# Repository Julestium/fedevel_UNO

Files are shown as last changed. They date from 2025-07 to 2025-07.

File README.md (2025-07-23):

# Arduino Uno Rev3 based PCB Design (Altium Designer)

This repository contains a complete **Arduino Uno Rev3 PCB design** based on the reference design from **Fedevel Academy**. It includes the full **schematic**, **PCB layout**, **assembly files**, **BOM (Bill of Materials)**, and **3D views**.

As part of my learning process, I manually recreated the schematic and implemented the PCB layout in Altium Designer. This project was intended as a personal exercise in schematic capture, layout, DRC management, variant handling, and preparing manufacturing outputs.

The goal of this project is to provide a **custom PCB design** that replicates the Arduino Uno Rev3 form factor and features, while offering a more professional approach to designing Arduino-based boards.

## Features
- Fully compatible with **Arduino Uno Rev3**
- Designed using **Altium Designer**
- Includes **3D view** of the PCB layout
- Detailed **schematic diagram** of the design
- Complete **Bill of Materials (BOM)**
- Ready-to-use **assembly files** for manufacturing

## Project Files
The following files are included in this repository:

- **Schematic**: Detailed circuit diagram in `.SchDoc` format
- **PCB Layout**: Fully routed PCB design in `.PcbDoc` format
- **Assembly Files**: Includes gerber files for manufacturing
- **BOM**: Complete Bill of Materials for easy component sourcing
- **3D View**: A 3D rendering of the PCB layout for visual inspection

### File Structure:
- `schematic/`: Contains the schematic design file (`.SchDoc`)
- `Assembly and 3D Models/`: Gerber files for PCB manufacturing , Bill of Materials and 3D render images of the PCB

### Schematic Diagram

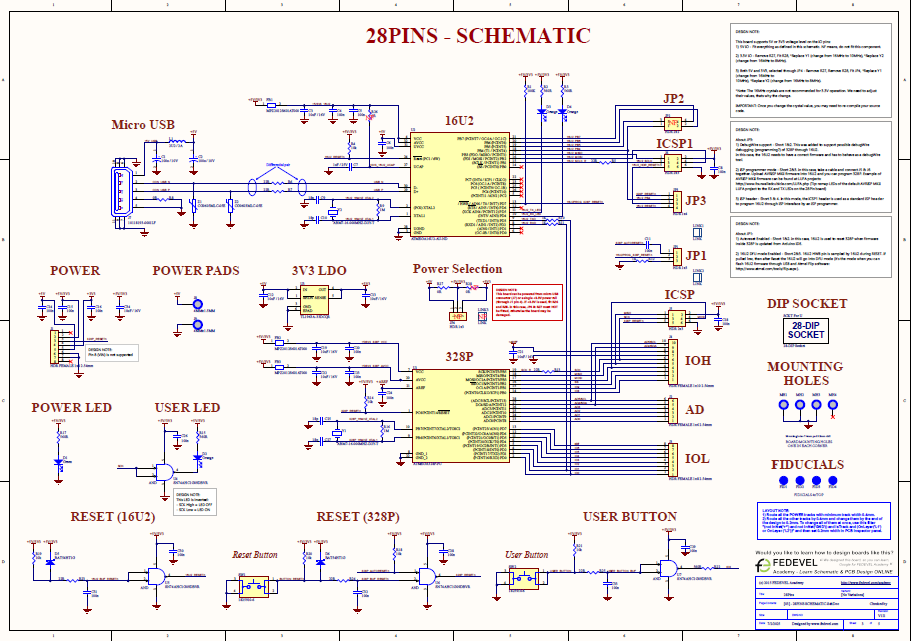
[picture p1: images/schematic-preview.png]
Schematic Preview
  

### PCB Layout

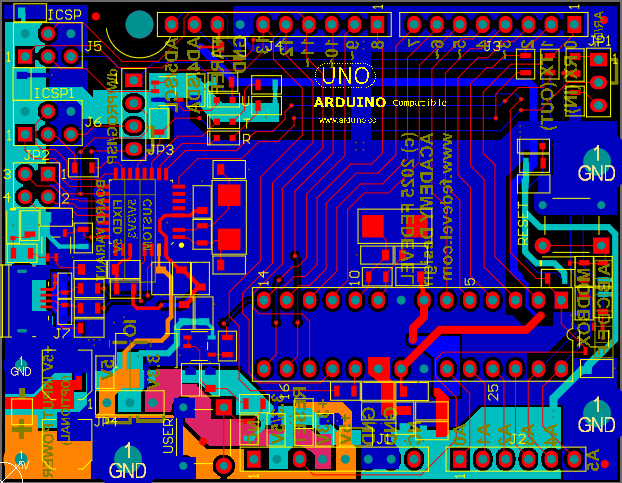
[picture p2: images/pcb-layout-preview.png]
PCB Layout Preview
  <!-- Image of PCB layout preview -->

### 3D View of the PCB

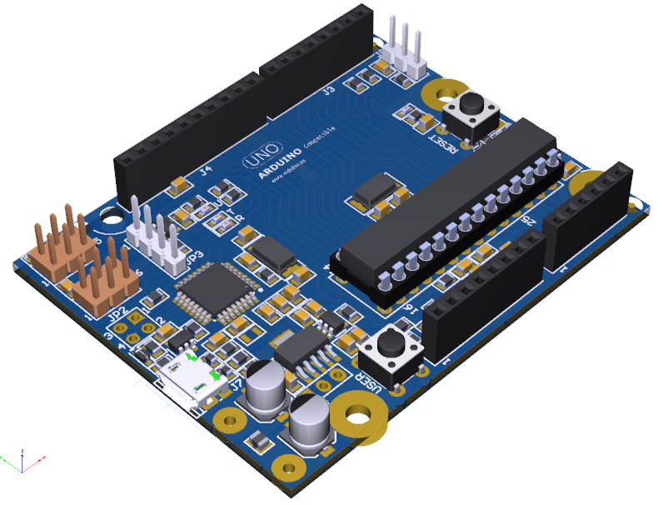
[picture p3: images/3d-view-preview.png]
3D View Preview
 

## Build Instructions

### Step 1: Manufacturing the PCB
1. Download the **Gerber files** from the `assembly/` folder.
2. Use these files to send to your preferred PCB manufacturer.

### Step 2: Assembling the Components
1. Once you have the PCB, begin the assembly by following the **Bill of Materials (BOM)**.
2. Solder the components according to the **schematic** and **PCB layout**.
3. Ensure all connections are made correctly, especially power and ground connections.

### Step 3: Testing the Board
Once the board is assembled:
1. Connect it to a computer or USB power supply.
2. Load the standard **Arduino Uno sketch** onto the board to verify that it functions correctly.

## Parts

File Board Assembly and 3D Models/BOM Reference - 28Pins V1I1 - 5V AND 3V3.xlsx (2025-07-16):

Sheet: Part List Report
 | Component reference list |  |  | 28Pins
 |  | Source Data From: | 28Pins_Project_V1I1.PrjPcb |  | Contact: |  | Generated by:
 |  | Project: | 28Pins_Project_V1I1.PrjPcb |  | LinkedIn (https://www.linkedin.com/in/mahla-gholami-4b0013294/)
 |  | Variant: | 5V/3V3 |  |  |  | M. Gholami
 | Report Date: | 7/1/2025 | 1:36 PM
 | Print Date: | 2025-07-01 | 14:52:56
# | Designator | Comment | Description | Manufacturer | Manufacturer Part Number | Case/Package | Supplier | Supplier Part Number
1 | C1 | 100u / 10V | Aluminum Electrolytic Capacitor, 100 uF, 10 V, ± 20%, 1000 hours @ 85°C, Radial Can - SMD | Panasonic | EEE-1AA101WR | Radial | Digikey | PCE3867CT-ND
2 | C2 | 100u / 10V | Aluminum Electrolytic Capacitor, 100 uF, 10 V, ± 20%, 1000 hours @ 85°C, Radial Can - SMD | Panasonic | EEE-1AA101WR | Radial | Digikey | PCE3867CT-ND
3 | C3 | 10uF / 16V | Multilayer Ceramic Capacitor, 10 uF, 16 V, ± 20%, X5R, 0805 [2012 Metric] | TDK | CGA4J1X5R1C106M125AC |  | Digikey | 445-12654-1-ND
4 | C4 | 100n | Multilayer Ceramic Capacitor, 0.1 uF, 50 V, ± 10%, X7R, 0805 [2012 Metric] | TDK | C2012X7R1H104K085AA | 0805 | Digikey | 445-7534-1-ND
5 | C5 | 100n | Multilayer Ceramic Capacitor, 0.1 uF, 50 V, ± 10%, X7R, 0805 [2012 Metric] | TDK | C2012X7R1H104K085AA | 0805 | Digikey | 445-7534-1-ND
6 | C6 | 100n | Multilayer Ceramic Capacitor, 0.1 uF, 50 V, ± 10%, X7R, 0805 [2012 Metric] | TDK | C2012X7R1H104K085AA | 0805 | Digikey | 445-7534-1-ND
7 | C7 | 1uF / 25V | CAP CER 1UF 25V X5R 0805 | TDK | C2012X5R1E105K125AA |  | Digikey | 445-1419-1-ND
8 | C8 | 100n | Multilayer Ceramic Capacitor, 0.1 uF, 50 V, ± 10%, X7R, 0805 [2012 Metric] | TDK | C2012X7R1H104K085AA | 0805 | Digikey | 445-7534-1-ND
9 | C9 | 18p | SMD Comm C0G 0805 (2012Metric) Ceramic Capacitor 0.079Lx0.049W 2.00mmx1.25mm C0G NP0 ±5% 18pF | KEMET | C0805C180J5GACTU | 0805 | Digikey | 399-C0805C180J5GACTUCT-ND
10 | C10 | 18p | SMD Comm C0G 0805 (2012Metric) Ceramic Capacitor 0.079Lx0.049W 2.00mmx1.25mm C0G NP0 ±5% 18pF | KEMET | C0805C180J5GACTU | 0805 | Digikey | 399-C0805C180J5GACTUCT-ND
11 | C11 | 100n | Multilayer Ceramic Capacitor, 0.1 uF, 50 V, ± 10%, X7R, 0805 [2012 Metric] | TDK | C2012X7R1H104K085AA | 0805 | Digikey | 445-7534-1-ND
12 | C12 | 10uF / 16V | Multilayer Ceramic Capacitor, 10 uF, 16 V, ± 20%, X5R, 0805 [2012 Metric] | TDK | CGA4J1X5R1C106M125AC |  | Digikey | 445-12654-1-ND
13 | C13 | 10uF / 16V | Multilayer Ceramic Capacitor, 10 uF, 16 V, ± 20%, X5R, 0805 [2012 Metric] | TDK | CGA4J1X5R1C106M125AC |  | Digikey | 445-12654-1-ND
14 | C14 | 100n | Multilayer Ceramic Capacitor, 0.1 uF, 50 V, ± 10%, X7R, 0805 [2012 Metric] | TDK | C2012X7R1H104K085AA | 0805 | Digikey | 445-7534-1-ND
15 | C15 | 100n | Multilayer Ceramic Capacitor, 0.1 uF, 50 V, ± 10%, X7R, 0805 [2012 Metric] | TDK | C2012X7R1H104K085AA | 0805 | Digikey | 445-7534-1-ND
16 | C16 | 100n | Multilayer Ceramic Capacitor, 0.1 uF, 50 V, ± 10%, X7R, 0805 [2012 Metric] | TDK | C2012X7R1H104K085AA | 0805 | Digikey | 445-7534-1-ND
17 | C18 | 100n | Multilayer Ceramic Capacitor, 0.1 uF, 50 V, ± 10%, X7R, 0805 [2012 Metric] | TDK | C2012X7R1H104K085AA | 0805 | Digikey | 445-7534-1-ND
18 | C19 | 10uF / 16V | Multilayer Ceramic Capacitor, 10 uF, 16 V, ± 20%, X5R, 0805 [2012 Metric] | TDK | CGA4J1X5R1C106M125AC |  | Digikey | 445-12654-1-ND
19 | C20 | 100n | Multilayer Ceramic Capacitor, 0.1 uF, 50 V, ± 10%, X7R, 0805 [2012 Metric] | TDK | C2012X7R1H104K085AA | 0805 | Digikey | 445-7534-1-ND
20 | C21 | 10uF / 16V | Multilayer Ceramic Capacitor, 10 uF, 16 V, ± 20%, X5R, 0805 [2012 Metric] | TDK | CGA4J1X5R1C106M125AC |  | Digikey | 445-12654-1-ND
21 | C22 | 10uF / 16V | Multilayer Ceramic Capacitor, 10 uF, 16 V, ± 20%, X5R, 0805 [2012 Metric] | TDK | CGA4J1X5R1C106M125AC |  | Digikey | 445-12654-1-ND
22 | C23 | 100n | Multilayer Ceramic Capacitor, 0.1 uF, 50 V, ± 10%, X7R, 0805 [2012 Metric] | TDK | C2012X7R1H104K085AA | 0805 | Digikey | 445-7534-1-ND
23 | C24 | 100n | Multilayer Ceramic Capacitor, 0.1 uF, 50 V, ± 10%, X7R, 0805 [2012 Metric] | TDK | C2012X7R1H104K085AA | 0805 | Digikey | 445-7534-1-ND
24 | C25 | 18p | SMD Comm C0G 0805 (2012Metric) Ceramic Capacitor 0.079Lx0.049W 2.00mmx1.25mm C0G NP0 ±5% 18pF | KEMET | C0805C180J5GACTU | 0805 | Digikey | 399-C0805C180J5GACTUCT-ND
25 | C26 | 100n | Multilayer Ceramic Capacitor, 0.1 uF, 50 V, ± 10%, X7R, 0805 [2012 Metric] | TDK | C2012X7R1H104K085AA | 0805 | Digikey | 445-7534-1-ND
26 | C27 | 18p | SMD Comm C0G 0805 (2012Metric) Ceramic Capacitor 0.079Lx0.049W 2.00mmx1.25mm C0G NP0 ±5% 18pF | KEMET | C0805C180J5GACTU | 0805 | Digikey | 399-C0805C180J5GACTUCT-ND
27 | C28 | 100n | Multilayer Ceramic Capacitor, 0.1 uF, 50 V, ± 10%, X7R, 0805 [2012 Metric] | TDK | C2012X7R1H104K085AA | 0805 | Digikey | 445-7534-1-ND
28 | C29 | 100n | Multilayer Ceramic Capacitor, 0.1 uF, 50 V, ± 10%, X7R, 0805 [2012 Metric] | TDK | C2012X7R1H104K085AA | 0805 | Digikey | 445-7534-1-ND
29 | C30 | 100n | Multilayer Ceramic Capacitor, 0.1 uF, 50 V, ± 10%, X7R, 0805 [2012 Metric] | TDK | C2012X7R1H104K085AA | 0805 | Digikey | 445-7534-1-ND
30 | C31 | 100n | Multilayer Ceramic Capacitor, 0.1 uF, 50 V, ± 10%, X7R, 0805 [2012 Metric] | TDK | C2012X7R1H104K085AA | 0805 | Digikey | 445-7534-1-ND
31 | C32 | 100n | Multilayer Ceramic Capacitor, 0.1 uF, 50 V, ± 10%, X7R, 0805 [2012 Metric] | TDK | C2012X7R1H104K085AA | 0805 | Digikey | 445-7534-1-ND
32 | C33 | 100n | Multilayer Ceramic Capacitor, 0.1 uF, 50 V, ± 10%, X7R, 0805 [2012 Metric] | TDK | C2012X7R1H104K085AA | 0805 | Digikey | 445-7534-1-ND
33 | C34 | 10uF / 16V | Multilayer Ceramic Capacitor, 10 uF, 16 V, ± 20%, X5R, 0805 [2012 Metric] | TDK | CGA4J1X5R1C106M125AC |  | Digikey | 445-12654-1-ND
34 | D1 | Green | Green 525nm LED Indication - Discrete 2.65V 0603 (1608 Metric) | Kingbright | APT1608LZGCK | 0603 | Digikey | 754-1934-1-ND
35 | D2 | Orange | LED Uni-Color Orange 2-Pin Chip 0603(1608Metric) T/R | Rohm | CSL1901DW1 |  | Digikey | 846-CSL1901DW1CT-ND
36 | D3 | Orange | LED Uni-Color Orange 2-Pin Chip 0603(1608Metric) T/R | Rohm | CSL1901DW1 |  | Digikey | 846-CSL1901DW1CT-ND
37 | D4 | Orange | LED Uni-Color Orange 2-Pin Chip 0603(1608Metric) T/R | Rohm | CSL1901DW1 |  | Digikey | 846-CSL1901DW1CT-ND
38 | D5 | BAT54HT1G | Small Signal Schottky Diode, Single, 30 V, 200 Ma, 800 Mv, 600 Ma, 150 C | ON Semiconductor / Fairchild | BAT54HT1G |  | Digikey | BAT54HT1GOSCT-ND
39 | D6 | BAT54HT1G | Small Signal Schottky Diode, Single, 30 V, 200 Ma, 800 Mv, 600 Ma, 150 C | ON Semiconductor / Fairchild | BAT54HT1G |  | Digikey | BAT54HT1GOSCT-ND
40 | FB1 | MPZ2012S601AT000 | Ferrite Beads Multi-Layer Power 600Ohm 25% 100MHz 2A 100mOhm DCR 0805 T/R | TDK | MPZ2012S601AT000 | 0805 | Digikey | 445-MPZ2012S601AT000CT-ND
41 | FB2 | MPZ2012S601AT000 | Ferrite Beads Multi-Layer Power 600Ohm 25% 100MHz 2A 100mOhm DCR 0805 T/R | TDK | MPZ2012S601AT000 | 0805 | Digikey | 445-MPZ2012S601AT000CT-ND
42 | FB3 | MPZ2012S601AT000 | Ferrite Beads Multi-Layer Power 600Ohm 25% 100MHz 2A 100mOhm DCR 0805 T/R | TDK | MPZ2012S601AT000 | 0805 | Digikey | 445-MPZ2012S601AT000CT-ND
43 | J1 | HDR FEMALE 1x8 2.54mm | 2.54mm (0.1") Pitch SIL Vertical PC Tail Socket Assembly, selective gold + tin, 8 contacts | Harwin | M20-7820842 | SIL | Digikey | 952-1823-ND
44 | J2 | HDR FEMALE 1x6 2.54mm | 2.54mm (0.1") Pitch SIL Vertical PC Tail Socket Assembly, tin, 6 contacts | Harwin | M20-7820646 | SIL | Digikey | 952-1809-ND
45 | J3 | HDR FEMALE 1x8 2.54mm | 2.54mm (0.1") Pitch SIL Vertical PC Tail Socket Assembly, selective gold + tin, 8 contacts | Harwin | M20-7820842 | SIL | Digikey | 952-1823-ND
46 | J4 | HDR FEMALE 1x10 2.54mm | 2.54mm (0.1") Pitch SIL Vertical PC Tail Socket Assembly, tin, 10 contacts | Harwin | M20-7821046 |  | Digikey | 952-1847-ND
47 | J5 | HDR 2x3 | Conn Unshrouded Header HDR 6 POS 2.54mm Solder ST Top Entry Thru-Hole BergStik® Bulk | Amphenol ICC / FCI | 67997-106HLF |  | Digikey | 609-3393-ND
48 | J6 | HDR 2x3 | Conn Unshrouded Header HDR 6 POS 2.54mm Solder ST Top Entry Thru-Hole BergStik® Bulk | Amphenol ICC / FCI | 67997-106HLF |  | Digikey | 609-3393-ND
49 | J7 | 10118193-0001LF | FCI Right Angle Surface Mount Mount Female USB Connector; 100 V ac; 1.8A | Amphenol ICC / FCI | 10118193-0001LF |  | Digikey | 609-4616-1-ND
50 | JP1 | HDR 1x3 | Conn Unshrouded Header HDR 3 POS 2.54mm Solder ST Top Entry Thru-Hole BergStik® Automotive Bulk | Amphenol ICC / FCI | 68000-103HLF |  | Digikey | 609-3461-ND
51 | JP3 | HDR 1x4 | Conn Unshrouded Header HDR 4 POS 2.54mm Solder ST Thru-Hole Bag | Amphenol ICC / FCI | 68001-204HLF |  | Digikey | 609-3402-ND
52 | JP4 | HDR 1x3 | Conn Unshrouded Header HDR 3 POS 2.54mm Solder ST Top Entry Thru-Hole BergStik® Automotive Bulk | Amphenol ICC / FCI | 68000-103HLF |  | Digikey | 609-3461-ND
53 | L1 | 2U2 / 2A | Inductor Power Shielded Wirewound 2.2uH 20% 1MHz Metal 1.4A 0.168Ohm DCR 0806 T/R | Murata | DFE201610P-2R2M=P2 | 0806 | Digikey | 490-10609-1-ND
54 | LINK1 | LINK | 2 Position 2.54 mm Centerline Single Circuit Open Top Jumper | Sullins | QPC02SXGN-RC |  | Digikey | S9337-ND
55 | LINK2 | LINK | 2 Position 2.54 mm Centerline Single Circuit Open Top Jumper | Sullins | QPC02SXGN-RC |  | Digikey | S9337-ND
56 | LINK3 | LINK | 2 Position 2.54 mm Centerline Single Circuit Open Top Jumper | Sullins | QPC02SXGN-RC |  | Digikey | S9337-ND
57 | R1 | 100K | 125Mw Thick Film Resistors 100Ppm/ 1% 100K 0805 Chip Resistor Surface Mount Rohs | Yageo | RC0805FR-07100KL | 0805 | Digikey | 311-100KCRCT-ND
58 | R2 | 560R | Res General Purpose Thick Film 0805 560 Ohm 1% 1/8W ±100ppm/°C Molded Paper T/R | Yageo | RC0805FR-07560RL |  | Digikey | 311-560CRCT-ND
59 | R3 | 560R | Res General Purpose Thick Film 0805 560 Ohm 1% 1/8W ±100ppm/°C Molded Paper T/R | Yageo | RC0805FR-07560RL |  | Digikey | 311-560CRCT-ND
60 | R4 | 10k | Res Thick Film 0805 10K Ohm 1% 0.125W(1/8W) +/-100ppm/C Epoxy Pad SMD T/R | Yageo | RC0805FR-0710KL | 0805 | Digikey | 311-10.0KCRCT-ND
61 | R5 | 22R | SMD Chip Resistor, 22 Ohm, ± 1%, 125 mW, 0805 [2012 Metric], Thick Film, General Purpose | Yageo | RC0805FR-0722RL |  | Digikey | 311-22.0CRCT-ND
62 | R6 | 22R | SMD Chip Resistor, 22 Ohm, ± 1%, 125 mW, 0805 [2012 Metric], Thick Film, General Purpose | Yageo | RC0805FR-0722RL |  | Digikey | 311-22.0CRCT-ND
63 | R7 | 22R | SMD Chip Resistor, 22 Ohm, ± 1%, 125 mW, 0805 [2012 Metric], Thick Film, General Purpose | Yageo | RC0805FR-0722RL |  | Digikey | 311-22.0CRCT-ND
64 | R8 | 0R | GENERAL PURPOSE CHIP RESISTOR Metal Glaze/thick Film, 0.125W, 0ohm, Surface Mount, 0805 | Yageo | RC0805JR-070RL | 0805 | Digikey | 311-0.0ARCT-ND
65 | R9 | 1M | 125Mw Thick Film Resistors 100Ppm/ 1% 1M 0805 Chip Resistor Surface Mount Rohs | Yageo | RC0805FR-071ML | Molded | Digikey | 311-1.00MCRCT-ND
66 | R10 | 1K | 125Mw Thick Film Resistors 100Ppm/ 1% 1K 0805 Chip Resistor Surface Mount Rohs | Yageo | RC0805FR-071KL | 0805 | Digikey | 311-1.00KCRCT-ND
67 | R11 | 1K | 125Mw Thick Film Resistors 100Ppm/ 1% 1K 0805 Chip Resistor Surface Mount Rohs | Yageo | RC0805FR-071KL | 0805 | Digikey | 311-1.00KCRCT-ND
68 | R12 | 1K | 125Mw Thick Film Resistors 100Ppm/ 1% 1K 0805 Chip Resistor Surface Mount Rohs | Yageo | RC0805FR-071KL | 0805 | Digikey | 311-1.00KCRCT-ND
69 | R13 | 22R | SMD Chip Resistor, 22 Ohm, ± 1%, 125 mW, 0805 [2012 Metric], Thick Film, General Purpose | Yageo | RC0805FR-0722RL |  | Digikey | 311-22.0CRCT-ND
70 | R14 | 10k | Res Thick Film 0805 10K Ohm 1% 0.125W(1/8W) +/-100ppm/C Epoxy Pad SMD T/R | Yageo | RC0805FR-0710KL | 0805 | Digikey | 311-10.0KCRCT-ND
71 | R15 | 560R | Res General Purpose Thick Film 0805 560 Ohm 1% 1/8W ±100ppm/°C Molded Paper T/R | Yageo | RC0805FR-07560RL |  | Digikey | 311-560CRCT-ND
72 | R16 | 1M | 125Mw Thick Film Resistors 100Ppm/ 1% 1M 0805 Chip Resistor Surface Mount Rohs | Yageo | RC0805FR-071ML | Molded | Digikey | 311-1.00MCRCT-ND
73 | R17 | 560R | Res General Purpose Thick Film 0805 560 Ohm 1% 1/8W ±100ppm/°C Molded Paper T/R | Yageo | RC0805FR-07560RL |  | Digikey | 311-560CRCT-ND
74 | R18 | 10k | Res Thick Film 0805 10K Ohm 1% 0.125W(1/8W) +/-100ppm/C Epoxy Pad SMD T/R | Yageo | RC0805FR-0710KL | 0805 | Digikey | 311-10.0KCRCT-ND
75 | R19 | 10k | Res Thick Film 0805 10K Ohm 1% 0.125W(1/8W) +/-100ppm/C Epoxy Pad SMD T/R | Yageo | RC0805FR-0710KL | 0805 | Digikey | 311-10.0KCRCT-ND
76 | R20 | 10k | Res Thick Film 0805 10K Ohm 1% 0.125W(1/8W) +/-100ppm/C Epoxy Pad SMD T/R | Yageo | RC0805FR-0710KL | 0805 | Digikey | 311-10.0KCRCT-ND
77 | R21 | 10k | Res Thick Film 0805 10K Ohm 1% 0.125W(1/8W) +/-100ppm/C Epoxy Pad SMD T/R | Yageo | RC0805FR-0710KL | 0805 | Digikey | 311-10.0KCRCT-ND
78 | R22 | 560R | Res General Purpose Thick Film 0805 560 Ohm 1% 1/8W ±100ppm/°C Molded Paper T/R | Yageo | RC0805FR-07560RL |  | Digikey | 311-560CRCT-ND
79 | R23 | 22R | SMD Chip Resistor, 22 Ohm, ± 1%, 125 mW, 0805 [2012 Metric], Thick Film, General Purpose | Yageo | RC0805FR-0722RL |  | Digikey | 311-22.0CRCT-ND
80 | R24 | 22R | SMD Chip Resistor, 22 Ohm, ± 1%, 125 mW, 0805 [2012 Metric], Thick Film, General Purpose | Yageo | RC0805FR-0722RL |  | Digikey | 311-22.0CRCT-ND
81 | R25 | 22R | SMD Chip Resistor, 22 Ohm, ± 1%, 125 mW, 0805 [2012 Metric], Thick Film, General Purpose | Yageo | RC0805FR-0722RL |  | Digikey | 311-22.0CRCT-ND
82 | SCKT For U | 28-DIP Socket | Socket DIP 28Cnts DualWipe 0.3InSpc. PhosphorBronze Nickel KinkedTail 4800Series | 3M 4828-3004-CP | 3M | 4828-3004-CP |  | Digikey | 3M5480-ND
83 | SW1 | 1825910-6 | Switch Tactile OFF (ON) SPST Round Button PC Pins 0.05A 24VDC 1.57N Thru-Hole Loose | TE Connectivity Alcoswitch | 1825910-6 |  | Digikey | 450-1650-ND
84 | SW2 | 1825910-6 | Switch Tactile OFF (ON) SPST Round Button PC Pins 0.05A 24VDC 1.57N Thru-Hole Loose | TE Connectivity Alcoswitch | 1825910-6 |  | Digikey | 450-1650-ND
85 | U1 | ATMEGA328P-PU | Microchip - ATMEGA328P-PU - Microcontroller Mcu, 8 Bit, Atmega, 20MHZ, DIP-28 | Microchip | ATMEGA328P-PU | 28-DIP (0.300", 7.62mm) | Digikey | ATMEGA328P-PU-ND
86 | U2 | ATMEGA16U2-AU-ND | Risc Microcontroller, 8-BIT, Flash, AVR Risc Cpu, 16MHZ, Cmos, PQFP32 | Microchip | ATMEGA16U2-AU | 32-TQFP | Digikey | ATMEGA16U2-AU-ND
87 | U3 | TL1963A-33DCQR | LDO Regulator Pos 3.3V 1.5A 6-Pin(5+Tab) SOT-223 T/R | Texas Instruments | TL1963A-33DCQR | SOT-223-6 | Digikey | 296-24534-1-ND
88 | U4 | SN74AHC1G09DBVR | 1-ch, 2-input 2-V to 5.5-V high-speed (9 ns) AND gate with open-drain outputs 5-SOT-23 -55 to 125 | Texas Instruments | SN74AHC1G09DBVR | SOT-23 | Digikey | 296-29202-1-ND
89 | U5 | SN74AHC1G09DBVR | 1-ch, 2-input 2-V to 5.5-V high-speed (9 ns) AND gate with open-drain outputs 5-SOT-23 -55 to 125 | Texas Instruments | SN74AHC1G09DBVR | SOT-23 | Digikey | 296-29202-1-ND
90 | U6 | SN74AHC1G09DBVR | 1-ch, 2-input 2-V to 5.5-V high-speed (9 ns) AND gate with open-drain outputs 5-SOT-23 -55 to 125 | Texas Instruments | SN74AHC1G09DBVR | SOT-23 | Digikey | 296-29202-1-ND
91 | U7 | SN74AHC1G09DBVR | 1-ch, 2-input 2-V to 5.5-V high-speed (9 ns) AND gate with open-drain outputs 5-SOT-23 -55 to 125 | Texas Instruments | SN74AHC1G09DBVR | SOT-23 | Digikey | 296-29202-1-ND
92 | Y1 |  | Crystal 10MHz ±20ppm (Tol) ±30ppm (Stability) 18pF FUND 80Ohm 2-Pin Mini-CSMD T/R | Abracon | ABM7-10.000MHZ-D2Y-T |  | Digikey | 535-9833-1-ND
93 | Y2 |  | Crystal 8MHz ±20ppm (Tol) ±30ppm (Stability) 18pF FUND 100Ohm 2-Pin Mini-CSMD T/R | Abracon | ABM7-8.000MHZ-D2Y-T |  | Digikey | 535-9831-1-ND
94 | Z1 | CG0603MLC-05E | ESD Suppressor Multilayer Varistor 5V Automotive 2-Pin Case 0603(1608Metric) T/R | Bourns | CG0603MLC-05E | 0603 | Digikey | CG0603MLC-05ECT-ND
95 | Z2 | CG0603MLC-05E | ESD Suppressor Multilayer Varistor 5V Automotive 2-Pin Case 0603(1608Metric) T/R | Bourns | CG0603MLC-05E | 0603 | Digikey | CG0603MLC-05ECT-ND
Approved |  |  |  | Notes

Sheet: Project Information
Project Full Path | E:\Elements\Apps\Altium\28Pins\!Design Files\V1I1\28Pins_Project_V1I1\28Pins_Project_V1I1.PrjPcb
Project Filename | 28Pins_Project_V1I1.PrjPcb
Variant Name | 5V/3V3
Data-Source Filename | 28Pins_Project_V1I1.PrjPcb
Data-Source Full Path | E:\Elements\Apps\Altium\28Pins\!Design Files\V1I1\28Pins_Project_V1I1\28Pins_Project_V1I1.PrjPcb
Title | 28Pins_Project_V1I1.PrjPcb
Total Quantity | 95
Report Time | 1:36 PM
Report Date | 7/1/2025
Report Date & Tine | 7/1/2025 1:36 PM
Output Name | 28Pins Component reference BOM
Output Type | BomReport
Output Generator Name | BOM
Output Generator Description | Bill of Materials

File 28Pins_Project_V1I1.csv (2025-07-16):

LIBRARYREFERENCE | FOOTPRINT1 | ACCURACY | ACTUATOR LENGTH | ACTUATOR MATERIAL | ACTUATOR TYPE | AVERAGE RECTIFIED CURRENT | BREAKDOWN VOLTAGE | CASE CODE (IMPERIAL) | CASE CODE (METRIC) | CASE/PACKAGE | CATEGORY | CLAMPING VOLTAGE | CLOCK FREQUENCY | COLOR | COMMENT | COMPONENTLINK10DESCRIPTION | COMPONENTLINK10URL | COMPONENTLINK11DESCRIPTION | COMPONENTLINK11URL | COMPONENTLINK1DESCRIPTION | COMPONENTLINK1URL | COMPONENTLINK2DESCRIPTION | COMPONENTLINK2URL | COMPONENTLINK3DESCRIPTION | COMPONENTLINK3URL | COMPONENTLINK4DESCRIPTION | COMPONENTLINK4URL | COMPONENTLINK5DESCRIPTION | COMPONENTLINK5URL | COMPONENTLINK6DESCRIPTION | COMPONENTLINK6URL | COMPONENTLINK7DESCRIPTION | COMPONENTLINK7URL | COMPONENTLINK8DESCRIPTION | COMPONENTLINK8URL | COMPONENTLINK9DESCRIPTION | COMPONENTLINK9URL | CONNECTOR TYPE | CONSTRUCTION | CONTACT CURRENT RATING | CONTACT FINISH - MATING | CONTACT GENDER | CONTACT MATERIAL | CONTACT MATING LENGTH | CONTACT PLATING | CONTACT POST LENGTH | CONTACT SHAPE | CONTACT TYPE | CORE ARCHITECTURE | CORE MATERIAL | CURRENT RATING | DATA BUS WIDTH | DC RESISTANCE (DCR) | DEPTH | DIAMETER | DIELECTRIC | DISSIPATION FACTOR | DOMINANT WAVELENGTH | DROPOUT VOLTAGE
10118193-0001LF | 10118193 |  |  |  |  |  |  |  |  |  | LDO |  |  | Black | 10118193-0001LF |  |  |  |  | https://cdn.amphenol-icc.com/media/wysiwyg/files/documentation/datasheet/inputoutput/io_usb_micro.pdf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 | https://cdn.amphenol-icc.com/media/wysiwyg/files/documentation/datasheet/inputoutput/io_usb_micro.pdf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 | https://cdn.amphenol-icc.com/media/wysiwyg/files/documentation/datasheet/inputoutput/io_usb_micro.pdf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 | https://cdn.amphenol-icc.com/media/wysiwyg/files/documentation/datasheet/inputoutput/io_usb_micro.pdf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 | https://cdn.amphenol-icc.com/media/wysiwyg/files/documentation/datasheet/inputoutput/io_usb_micro.pdf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 | https://cdn.amphenol-icc.com/media/wysiwyg/files/documentation/datasheet/inputoutput/io_usb_micro.pdf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 | https://datasheet.octopart.com/10118193-0001LF-Amphenol-Communications-Solutions-datasheet-96019471.pdf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 | https://datasheet.octopart.com/10118193-0001LF-Amphenol-Communications-Solutions-datasheet-96019471.pdf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 | https://cdn.amphenol-icc.com/media/wysiwyg/files/documentation/datasheet/inputoutput/io_usb_micro.pdf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 | https://cdn.amphenol-icc.com/media/wysiwyg/files/documentation/datasheet/inputoutput/io_usb_micro.pdf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 | https://cdn.amphenol-icc.com/media/wysiwyg/files/documentation/datasheet/inputoutput/io_usb_micro.pdf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 | https://cdn.amphenol-icc.com/media/wysiwyg/files/documentation/datasheet/inputoutput/io_usb_micro.pdf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 | https://datasheet.octopart.com/10118193-0001LF-Amphenol-Communications-Solutions-datasheet-11792339.pdf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 | https://datasheet.octopart.com/10118193-0001LF-Amphenol-Communications-Solutions-datasheet-11792339.pdf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 | https://datasheet.octopart.com/10118193-0001LF-Amphenol-Communications-Solutions-datasheet-55953155.pdf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 | https://datasheet.octopart.com/10118193-0001LF-Amphenol-Communications-Solutions-datasheet-55953155.pdf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 |  |  | USB,Receptacle |  |  |  |  | Copper Alloy |  | Gold |  |  |  |  |  | 1.8A |  |  | 5.67mm
1825910-6 | 1825910-6 |  | 0.055inch | PBT | Standard |  |  |  |  |  | Pushbutton Switches |  |  | 46Colour | 1825910-6 |  |  |  |  |  |  |  |  |  |  |  |  |  |  |  |  |  |  |  |  |  |  |  |  | 50mA |  |  | Copper Alloy |  | Silver |  |  |  |  |  | 50mA
4828-3004-CP | 28-DIP_7.62mm_SOCKET |  |  |  |  |  |  |  |  |  | Connectors |  |  |  | 28-DIP Socket |  |  |  |  | https://datasheet.ciiva.com/768/ts1099-768354.pdf?src-supplier=Digikey | https://datasheet.ciiva.com/768/ts1099-768354.pdf?src-supplier=Digikey
67997-106HLF | HDR_2X3_2.54mm |  |  |  |  |  |  |  |  |  | Headers and Wire Housings |  |  |  | HDR 2x3 | https://cdn.amphenol-icc.com/media/wysiwyg/files/drawing/67996.pdf?src-supplier=TTI | https://cdn.amphenol-icc.com/media/wysiwyg/files/drawing/67996.pdf?src-supplier=TTI | https://cdn.amphenol-icc.com/media/wysiwyg/files/drawing/67996.pdf?src-supplier=Heilind+Electronics | https://cdn.amphenol-icc.com/media/wysiwyg/files/drawing/67996.pdf?src-supplier=Heilind+Electronics | http://uk.rs-online.com/webdocs/1450/0900766b81450b8b.pdf?src-supplier=Rs | http://uk.rs-online.com/webdocs/1450/0900766b81450b8b.pdf?src-supplier=Rs | https://datasheet.octopart.com/67997-106HLF-Areva-datasheet-118652.pdf?src-supplier=Digikey | https://datasheet.octopart.com/67997-106HLF-Areva-datasheet-118652.pdf?src-supplier=Digikey | https://datasheet.octopart.com/67997-106HLF-Amphenol-Communications-Solutions-datasheet-36854132.pdf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 | https://datasheet.octopart.com/67997-106HLF-Amphenol-Communications-Solutions-datasheet-36854132.pdf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 | https://cdn.amphenol-icc.com/media/wysiwyg/files/drawing/67996.pdf?src-supplier=Mouser | https://cdn.amphenol-icc.com/media/wysiwyg/files/drawing/67996.pdf?src-supplier=Mouser | https://cdn.amphenol-icc.com/media/wysiwyg/files/drawing/67996.pdf?src-supplier=Avnet | https://cdn.amphenol-icc.com/media/wysiwyg/files/drawing/67996.pdf?src-supplier=Avnet | http://components.arrow.com/part/dataview/41913658S7633350N8314?src-supplier=Arrow+Electronics | http://components.arrow.com/part/dataview/41913658S7633350N8314?src-supplier=Arrow+Electronics | https://cdn.amphenol-icc.com/media/wysiwyg/files/drawing/67996.pdf?src-supplier=Onlinecomponents.com | https://cdn.amphenol-icc.com/media/wysiwyg/files/drawing/67996.pdf?src-supplier=Onlinecomponents.com | http://www.farnell.com/datasheets/1876884.pdf?src-supplier=Newark | http://www.farnell.com/datasheets/1876884.pdf?src-supplier=Newark | https://cdn.amphenol-icc.com/media/wysiwyg/files/drawing/67996.pdf?src-supplier=Allied+Electronics | https://cdn.amphenol-icc.com/media/wysiwyg/files/drawing/67996.pdf?src-supplier=Allied+Electronics
68000-103HLF | Hdr_1x3_2.54mm |  |  |  |  |  |  |  |  |  | Headers and Wire Housings |  |  |  | HDR 1x3 |  |  |  |  | https://datasheet.ciiva.com/46392/1914865-46392021.pdf?src-supplier=Element14 | https://datasheet.ciiva.com/46392/1914865-46392021.pdf?src-supplier=Element14
68001-204HLF | HDR_1x4_2.54mm |  |  |  |  |  |  |  |  |  | Headers and Wire Housings |  |  | Black | HDR 1x4 | https://cdn.amphenol-icc.com/media/wysiwyg/files/drawing/68000.pdf?src-supplier=Heilind+Electronics | https://cdn.amphenol-icc.com/media/wysiwyg/files/drawing/68000.pdf?src-supplier=Heilind+Electronics | https://datasheet.octopart.com/68001-204HLF-Amphenol-Communications-Solutions-datasheet-154727322.pdf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 | https://datasheet.octopart.com/68001-204HLF-Amphenol-Communications-Solutions-datasheet-154727322.pdf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 | http://uk.rs-online.com/webdocs/1450/0900766b81450c68.pdf?src-supplier=Rs | http://uk.rs-online.com/webdocs/1450/0900766b81450c68.pdf?src-supplier=Rs | http://components.arrow.com/part/dataview/42735081S8853857N8314?src-supplier=Arrow+Electronics | http://components.arrow.com/part/dataview/42735081S8853857N8314?src-supplier=Arrow+Electronics | https://cdn.amphenol-icc.com/media/wysiwyg/files/drawing/68000.pdf?src-supplier=Avnet | https://cdn.amphenol-icc.com/media/wysiwyg/files/drawing/68000.pdf?src-supplier=Avnet | https://cdn.amphenol-icc.com/media/wysiwyg/files/drawing/68000.pdf?src-supplier=Allied+Electronics | https://cdn.amphenol-icc.com/media/wysiwyg/files/drawing/68000.pdf?src-supplier=Allied+Electronics | https://datasheet.octopart.com/68001-204HLF-Amphenol-Communications-Solutions-datasheet-100449246.pdf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 | https://datasheet.octopart.com/68001-204HLF-Amphenol-Communications-Solutions-datasheet-100449246.pdf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 | https://cdn.amphenol-icc.com/media/wysiwyg/files/drawing/68000.pdf?src-supplier=Digikey | https://cdn.amphenol-icc.com/media/wysiwyg/files/drawing/68000.pdf?src-supplier=Digikey | https://datasheet.octopart.com/68001-204HLF-Amphenol-Communications-Solutions-datasheet-41232361.pdf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 | https://datasheet.octopart.com/68001-204HLF-Amphenol-Communications-Solutions-datasheet-41232361.pdf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 | https://cdn.amphenol-icc.com/media/wysiwyg/files/drawing/68000.pdf?src-supplier=Mouser | https://cdn.amphenol-icc.com/media/wysiwyg/files/drawing/68000.pdf?src-supplier=Mouser | https://cdn.amphenol-icc.com/media/wysiwyg/files/drawing/68000.pdf?src-supplier=TTI | https://cdn.amphenol-icc.com/media/wysiwyg/files/drawing/68000.pdf?src-supplier=TTI |  |  |  |  | Male | Bronze | 0.23inch | Gold,GXT | 3.05mm |  | Male Pin |  |  | 3A
68602-204HLF | HDR_2X2_2.54MM |  |  |  |  |  |  |  |  |  |  |  |  |  | HDR 2x2
ABM7-10.000MHZ-D2Y-T | ABM7_v1_1_big |  |  |  |  |  |  |  |  |  | Crystals |  |  |  | ABM7-10.000MHZ-D2Y-T |  |  |  |  | https://datasheet.ciiva.com/16397/abm7-16397372.pdf?src-supplier=Future+Electronics | https://datasheet.ciiva.com/16397/abm7-16397372.pdf?src-supplier=Future+Electronics
ABM7-16.000MHZ-D2Y-T | ABM7_v1_1_big |  |  |  |  |  |  |  |  | CSMD | Crystals |  |  |  | ABM7-16.000MHZ-D2Y-T | https://datasheet.ciiva.com/26941/getdatasheetpartid-719818-26941724.pdf?src-supplier=Verical | https://datasheet.ciiva.com/26941/getdatasheetpartid-719818-26941724.pdf?src-supplier=Verical |  |  | https://datasheet.ciiva.com/15116/getdatasheetpartid-721624-15116835.pdf?src-supplier=Verical | https://datasheet.ciiva.com/15116/getdatasheetpartid-721624-15116835.pdf?src-supplier=Verical | https://datasheet.ciiva.com/5788/abm7-5788054.pdf?src-supplier=Farnell | https://datasheet.ciiva.com/5788/abm7-5788054.pdf?src-supplier=Farnell | https://datasheet.ciiva.com/7998/947971-7998600.pdf?src-supplier=Element14 | https://datasheet.ciiva.com/7998/947971-7998600.pdf?src-supplier=Element14 | https://datasheet.ciiva.com/22658/947971-22658293.pdf?src-supplier=Element14 | https://datasheet.ciiva.com/22658/947971-22658293.pdf?src-supplier=Element14 | https://datasheet.ciiva.com/46385/947971-46385243.pdf?src-supplier=Element14 | https://datasheet.ciiva.com/46385/947971-46385243.pdf?src-supplier=Element14 | https://datasheet.ciiva.com/18649/abm7-18649866.pdf?src-supplier=Digikey | https://datasheet.ciiva.com/18649/abm7-18649866.pdf?src-supplier=Digikey | https://datasheet.ciiva.com/18649/abm7-18649865.pdf?src-supplier=Digikey | https://datasheet.ciiva.com/18649/abm7-18649865.pdf?src-supplier=Digikey | https://datasheet.ciiva.com/18649/abm7-18649867.pdf?src-supplier=Digikey | https://datasheet.ciiva.com/18649/abm7-18649867.pdf?src-supplier=Digikey | https://datasheet.ciiva.com/16383/abm7-16383174.pdf?src-supplier=Future+Electronics | https://datasheet.ciiva.com/16383/abm7-16383174.pdf?src-supplier=Future+Electronics |  |  |  |  |  |  |  |  |  |  |  |  |  |  |  |  | 3.5mm
ABM7-8.000MHZ-D2Y-T | ABM7_v1_1_big |  |  |  |  |  |  |  |  |  | Crystals |  |  |  | ABM7-8.000MHZ-D2Y-T |  |  |  |  | https://datasheet.ciiva.com/15116/getdatasheetpartid-722403-15116844.pdf?src-supplier=Verical | https://datasheet.ciiva.com/15116/getdatasheetpartid-722403-15116844.pdf?src-supplier=Verical | https://datasheet.ciiva.com/1357/1718755-1357277.pdf?src-supplier=Element14 | https://datasheet.ciiva.com/1357/1718755-1357277.pdf?src-supplier=Element14 | https://datasheet.ciiva.com/16416/abm7-16416924.pdf?src-supplier=Future+Electronics | https://datasheet.ciiva.com/16416/abm7-16416924.pdf?src-supplier=Future+Electronics | https://datasheet.ciiva.com/4944/abm7-19096-4944987.pdf?src-supplier=Mouser | https://datasheet.ciiva.com/4944/abm7-19096-4944987.pdf?src-supplier=Mouser | https://datasheet.ciiva.com/29998/abm7-29998171.pdf?src-supplier=Avnet | https://datasheet.ciiva.com/29998/abm7-29998171.pdf?src-supplier=Avnet
APT1608LZGCK | LED_0603 |  |  |  |  |  |  | 0603 | 1608 | 0603 | LEDs |  |  | Green | Green |  |  |  |  | http://www.mouser.com/ds/2/216/APT1608LZGCK-535830.pdf?src-supplier=Mouser | http://www.mouser.com/ds/2/216/APT1608LZGCK-535830.pdf?src-supplier=Mouser | http://www.kingbrightusa.com/images/catalog/SPEC/APT1608LZGCK.pdf?src-supplier=Digikey | http://www.kingbrightusa.com/images/catalog/SPEC/APT1608LZGCK.pdf?src-supplier=Digikey |  |  |  |  |  |  |  |  |  |  |  |  |  |  |  |  |  |  |  |  |  |  |  |  |  |  |  |  |  |  |  |  |  |  | 525nm
ATMEGA16U2-AU | TQFP32 |  |  |  |  |  |  |  |  | A | Microcontrollers |  | 16MHz |  | ATMEGA16U2-AU-ND |  |  |  |  | https://datasheet.ciiva.com/13036/doc7799-28769-13036800.pdf?src-supplier=Mouser | https://datasheet.ciiva.com/13036/doc7799-28769-13036800.pdf?src-supplier=Mouser | https://datasheet.ciiva.com/22651/doc7799-22651110.pdf?src-supplier=Farnell | https://datasheet.ciiva.com/22651/doc7799-22651110.pdf?src-supplier=Farnell |  |  |  |  |  |  |  |  |  |  |  |  |  |  |  |  |  |  |  |  |  |  |  |  |  | AVR |  |  | 8b
ATMEGA328P-PU | 28_DIP_7.62mm |  |  |  |  |  |  |  |  | PDIP |  |  | 20MHz |  | ATMEGA328P-PU |  |  |  |  | https://datasheet.ciiva.com/19457/2139111-19457070.pdf?src-supplier=Jameco | https://datasheet.ciiva.com/19457/2139111-19457070.pdf?src-supplier=Jameco | https://datasheet.ciiva.com/1157/1684409-1157696.pdf?src-supplier=Element14 | https://datasheet.ciiva.com/1157/1684409-1157696.pdf?src-supplier=Element14 | https://datasheet.ciiva.com/29119/155197-da-01-en-microcontr-atmega328p-pu-8bit-pdip-28-29119593.pdf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 | https://datasheet.ciiva.com/29119/155197-da-01-en-microcontr-atmega328p-pu-8bit-pdip-28-29119593.pdf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 | https://datasheet.ciiva.com/15213/getdatasheetpartid-318533-15213133.pdf?src-supplier=Verical | https://datasheet.ciiva.com/15213/getdatasheetpartid-318533-15213133.pdf?src-supplier=Verical |  |  |  |  |  |  |  |  |  |  |  |  |  |  |  |  |  |  |  |  |  | AVR |  |  | 8b
BAT54HT1G | SOD323 |  |  |  |  | 200mA | 30V |  |  |  | Schottky Diodes |  |  |  | BAT54HT1G |  |  |  |  | https://datasheet.ciiva.com/4452/bat54ht1g-104602-4452889.pdf?src-supplier=Mouser | https://datasheet.ciiva.com/4452/bat54ht1g-104602-4452889.pdf?src-supplier=Mouser | https://datasheet.ciiva.com/30479/0900766b811a63a9-30479442.pdf?src-supplier=Rs | https://datasheet.ciiva.com/30479/0900766b811a63a9-30479442.pdf?src-supplier=Rs | https://datasheet.ciiva.com/34301/806549-34301562.pdf?src-supplier=Jameco | https://datasheet.ciiva.com/34301/806549-34301562.pdf?src-supplier=Jameco | https://datasheet.ciiva.com/1240/1747983-1240762.pdf?src-supplier=Newark | https://datasheet.ciiva.com/1240/1747983-1240762.pdf?src-supplier=Newark | https://datasheet.ciiva.com/4714/bat54ht1-d-72881-4714706.pdf?src-supplier=Mouser | https://datasheet.ciiva.com/4714/bat54ht1-d-72881-4714706.pdf?src-supplier=Mouser | https://datasheet.ciiva.com/1180/bat54ht1-d-1180251.pdf?src-supplier=Element14 | https://datasheet.ciiva.com/1180/bat54ht1-d-1180251.pdf?src-supplier=Element14 | https://datasheet.ciiva.com/1180/bat54ht1-d-1180252.pdf?src-supplier=Element14 | https://datasheet.ciiva.com/1180/bat54ht1-d-1180252.pdf?src-supplier=Element14 | https://datasheet.ciiva.com/46429/1727620-46429206.pdf?src-supplier=Element14 | https://datasheet.ciiva.com/46429/1727620-46429206.pdf?src-supplier=Element14 | https://datasheet.ciiva.com/48686/001262925-da-01-en-diode-schottky-30v-bat54ht1g-sod-323-fsc-48686266.pdf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 | https://datasheet.ciiva.com/48686/001262925-da-01-en-diode-schottky-30v-bat54ht1g-sod-323-fsc-48686266.pdf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 |  |  |  |  |  |  |  | Tin,Matte |  |  |  |  |  | 200mA
C0805C180J5GACTU | C0805 - 1.45Height |  |  |  |  |  |  | 0805 | 2012 | 0805 | Ceramic Capacitors |  |  |  | 18p |  |  |  |  | https://datasheet.ciiva.com/26923/getdatasheetpartid-759702-26923980.pdf?src-supplier=Verical | https://datasheet.ciiva.com/26923/getdatasheetpartid-759702-26923980.pdf?src-supplier=Verical |  |  |  |  |  |  |  |  |  |  |  |  |  |  |  |  |  | Flat |  |  |  |  |  |  |  |  |  |  |  |  |  |  | 1.25mm |  | C0G | 0.1%
C2012X5R1E105K125AA | C0805 - 1.45Height |  |  |  |  |  |  |  |  |  | Ceramic Capacitors |  |  |  | 1uF / 25V |  |  |  |  | https://datasheet.ciiva.com/11787/0900766b80c1bb00-11787608.pdf?src-supplier=Rs | https://datasheet.ciiva.com/11787/0900766b80c1bb00-11787608.pdf?src-supplier=Rs | https://datasheet.ciiva.com/16449/e412-c-16449595.pdf?src-supplier=Future+Electronics | https://datasheet.ciiva.com/16449/e412-c-16449595.pdf?src-supplier=Future+Electronics | https://datasheet.ciiva.com/15192/getdatasheetpartid-726707-15192140.pdf?src-supplier=Verical | https://datasheet.ciiva.com/15192/getdatasheetpartid-726707-15192140.pdf?src-supplier=Verical | https://datasheet.ciiva.com/28602/1744655-28602171.pdf?src-supplier=Element14 | https://datasheet.ciiva.com/28602/1744655-28602171.pdf?src-supplier=Element14
C2012X7R1H104K085AA | C0805 |  |  |  |  |  |  | 0805 | 2012 | 0805 | Ceramic Capacitors |  |  |  | 100n |  |  |  |  | https://datasheet.ciiva.com/11788/0900766b80c1bb00-11788128.pdf?src-supplier=Rs | https://datasheet.ciiva.com/11788/0900766b80c1bb00-11788128.pdf?src-supplier=Rs | https://datasheet.ciiva.com/6250/tdkmlcccaprange-6250821.pdf?src-supplier=Digikey | https://datasheet.ciiva.com/6250/tdkmlcccaprange-6250821.pdf?src-supplier=Digikey | https://datasheet.ciiva.com/6250/tdkmlcccaprange-6250824.pdf?src-supplier=Digikey | https://datasheet.ciiva.com/6250/tdkmlcccaprange-6250824.pdf?src-supplier=Digikey | https://datasheet.ciiva.com/23803/1796654-23803035.pdf?src-supplier=Newark | https://datasheet.ciiva.com/23803/1796654-23803035.pdf?src-supplier=Newark | https://datasheet.ciiva.com/28602/1571323-28602204.pdf?src-supplier=Element14 | https://datasheet.ciiva.com/28602/1571323-28602204.pdf?src-supplier=Element14 | https://datasheet.ciiva.com/24191/e412-c-24191447.pdf?src-supplier=Future+Electronics | https://datasheet.ciiva.com/24191/e412-c-24191447.pdf?src-supplier=Future+Electronics |  |  |  |  |  |  |  |  |  |  |  |  |  |  |  |  |  |  |  |  |  |  | 1.25mm |  | X7R
CG0603MLC-05E | R0603 |  |  |  |  |  |  | 0603 | 1608 | 0603 | Varistors | 20V |  |  | CG0603MLC-05E |  |  |  |  | https://datasheet.ciiva.com/27747/1163231-27747629.pdf?src-supplier=Jameco | https://datasheet.ciiva.com/27747/1163231-27747629.pdf?src-supplier=Jameco | https://datasheet.ciiva.com/8084/mlc-8084047.pdf?src-supplier=Avnet | https://datasheet.ciiva.com/8084/mlc-8084047.pdf?src-supplier=Avnet | https://datasheet.ciiva.com/6991/mlc-6991834.pdf?src-supplier=Digikey | https://datasheet.ciiva.com/6991/mlc-6991834.pdf?src-supplier=Digikey | https://datasheet.ciiva.com/6991/mlc-6991836.pdf?src-supplier=Digikey | https://datasheet.ciiva.com/6991/mlc-6991836.pdf?src-supplier=Digikey | https://datasheet.ciiva.com/6991/mlc-6991832.pdf?src-supplier=Digikey | https://datasheet.ciiva.com/6991/mlc-6991832.pdf?src-supplier=Digikey |  |  |  |  |  |  |  |  |  |  |  |  |  |  |  | Tin |  |  |  |  |  | 50nA |  |  | 0.8mm
CGA4J1X5R1C106M125AC | C0805 - 1.45Height |  |  |  |  |  |  |  |  |  | Ceramic Capacitors |  |  |  | 10uF / 16V |  |  |  |  | http://product.tdk.com/en/catalog/datasheets/mlcc_automotive_general_en.pdf?src-supplier=Avnet | http://product.tdk.com/en/catalog/datasheets/mlcc_automotive_general_en.pdf?src-supplier=Avnet | http://product.tdk.com/capacitor/mlcc/detailed_information.php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 | http://product.tdk.com/capacitor/mlcc/detailed_information.php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 | https://product.tdk.com/info/en/catalog/datasheets/mlcc_automotive_general_en.pdf?src-supplier=Digikey | https://product.tdk.com/info/en/catalog/datasheets/mlcc_automotive_general_en.pdf?src-supplier=Digikey | https://product.tdk.com/info/en/documents/chara_sheet/CGA4J1X5R1C106M125AC.pdf?src-supplier=Digikey | https://product.tdk.com/info/en/documents/chara_sheet/CGA4J1X5R1C106M125AC.pdf?src-supplier=Digikey
CSL1901DW1 | LED_0603 |  |  |  |  |  |  |  |  |  | LEDs |  |  |  | Orange
Component_1 |  |  |  |  |  |  |  |  |  |  |  |  |  |  | *
DFE201610P-2R2M=P2 | 2016_IND |  |  |  |  |  |  | 0806 | 2016 | 0806 | Fixed Inductors |  |  |  | 2U2 / 2A |  |  |  |  | http://farnell.com//datasheets/2550119.pdf?src-supplier=Farnell | http://farnell.com//datasheets/2550119.pdf?src-supplier=Farnell | https://www.murata.com/~/media/webrenewal/products/inductor/chip/tokoproducts/wirewoundmetalalloychiptype/m_dfe201610p.ashx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 | https://www.murata.com/~/media/webrenewal/products/inductor/chip/tokoproducts/wirewoundmetalalloychiptype/m_dfe201610p.ashx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 |  |  |  |  |  |  |  |  |  |  |  |  |  |  |  |  |  |  |  |  |  |  |  |  |  |  | Ferrite | 2A |  | 168mR
EEE-1AA101WR | C_ALU_C_SIZE |  |  |  |  |  |  |  |  | Radial | Aluminum Electrolytic Capacitors |  |  |  | 100u / 10V |  |  |  |  | https://datasheet.ciiva.com/26945/getdatasheetpartid-169213-26945071.pdf?src-supplier=Verical | https://datasheet.ciiva.com/26945/getdatasheetpartid-169213-26945071.pdf?src-supplier=Verical | https://datasheet.ciiva.com/24027/aba0000ce2-40801-24027541.pdf?src-supplier=Mouser | https://datasheet.ciiva.com/24027/aba0000ce2-40801-24027541.pdf?src-supplier=Mouser | https://datasheet.ciiva.com/14598/70255710-14598233.pdf?src-supplier=Allied+Electronics | https://datasheet.ciiva.com/14598/70255710-14598233.pdf?src-supplier=Allied+Electronics | https://datasheet.ciiva.com/14605/70255710-14605689.pdf?src-supplier=Allied+Electronics | https://datasheet.ciiva.com/14605/70255710-14605689.pdf?src-supplier=Allied+Electronics | https://datasheet.ciiva.com/11673/aba0000ce2-11673882.pdf?src-supplier=Avnet | https://datasheet.ciiva.com/11673/aba0000ce2-11673882.pdf?src-supplier=Avnet | https://datasheet.ciiva.com/16427/aba0000ce2-16427544.pdf?src-supplier=Future+Electronics | https://datasheet.ciiva.com/16427/aba0000ce2-16427544.pdf?src-supplier=Future+Electronics |  |  |  |  |  |  |  | Cylindrical |  |  |  |  |  |  |  |  |  |  |  |  |  |  |  | 5mm |  | 30%
FID_1MMC | FID_40x120D |  |  |  |  |  |  |  |  |  |  |  |  |  | FID_1MMC
M20-7820646 | Hdr_Female_1x6_2.54mm |  |  |  |  |  |  |  |  | SIL | Headers and Wire Housings |  |  |  | HDR FEMALE 1x6 2.54mm |  |  |  |  | https://cdn.harwin.com/pdfs/Harwin_PC_Connectors_M20.pdf?src-supplier=Rs | https://cdn.harwin.com/pdfs/Harwin_PC_Connectors_M20.pdf?src-supplier=Rs | http://www.harwin.com/include/downloads/pdfs/2010PAGE120.PDF?src-supplier=Avnet | http://www.harwin.com/include/downloads/pdfs/2010PAGE120.PDF?src-supplier=Avnet | https://cdn.harwin.com/pdfs/M20-782.pdf?src-supplier=Digikey | https://cdn.harwin.com/pdfs/M20-782.pdf?src-supplier=Digikey | https://cdn.harwin.com/pdfs/Harwin_PC_Connectors_M20.pdf?src-supplier=Mouser | https://cdn.harwin.com/pdfs/Harwin_PC_Connectors_M20.pdf?src-supplier=Mouser | https://cdn.harwin.com/pdfs/Harwin_PC_Connectors_M20.pdf?src-supplier=TTI | https://cdn.harwin.com/pdfs/Harwin_PC_Connectors_M20.pdf?src-supplier=TTI |  |  |  |  |  |  |  |  | Receptacle |  |  | TIN | Female | Bronze |  | Tin |  | Square | Female Socket
M20-7820842 | Hdr_Female_1x8_2.54mm |  |  |  |  |  |  |  |  | SIL | Headers and Wire Housings |  |  |  | HDR FEMALE 1x8 2.54mm |  |  |  |  | https://datasheet.ciiva.com/9480/m20-782-9480074.pdf?src-supplier=Avnet | https://datasheet.ciiva.com/9480/m20-782-9480074.pdf?src-supplier=Avnet |  |  |  |  |  |  |  |  |  |  |  |  |  |  |  |  | Receptacle |  |  | GOLD | Female | Bronze |  | Tin,Gold |  | Square | Female Socket
M20-7821046 | Hdr_Female_1x10_2.54mm |  |  |  |  |  |  |  |  |  | Headers and Wire Housings |  |  |  | HDR FEMALE 1x10 2.54mm |  |  |  |  | https://datasheet.ciiva.com/11753/0900766b80dc1d2b-11753869.pdf?src-supplier=Rs | https://datasheet.ciiva.com/11753/0900766b80dc1d2b-11753869.pdf?src-supplier=Rs | https://datasheet.ciiva.com/26899/getdatasheetpartid-559226-26899379.pdf?src-supplier=Verical | https://datasheet.ciiva.com/26899/getdatasheetpartid-559226-26899379.pdf?src-supplier=Verical | https://datasheet.ciiva.com/6785/m20-782-6785605.pdf?src-supplier=Digikey | https://datasheet.ciiva.com/6785/m20-782-6785605.pdf?src-supplier=Digikey | https://datasheet.ciiva.com/10151/m20-782-10151366.pdf?src-supplier=Avnet | https://datasheet.ciiva.com/10151/m20-782-10151366.pdf?src-supplier=Avnet
MH_7.4MMC_3.2MMD | MH_7.4MMD_3.2MMD |  |  |  |  |  |  |  |  |  |  |  |  |  | MH_7.4MMC_3.2MMD
MH_7.4MMNC_3.2MMD | MH_7.4MMD_3.2MMD_NON_COPPER_NPTH |  |  |  |  |  |  |  |  |  |  |  |  |  | MH_7.4MMNC_3.2MMD
MPZ2012S601AT000 | C0805 |  |  |  |  |  |  | 0805 | 2012 | 0805 | Ferrite Beads and Chips |  |  |  | MPZ2012S601AT000 |  |  |  |  | https://datasheet.ciiva.com/46634/beads-commercial-power-mpz-en-46634335.pdf?src-supplier=Digikey | https://datasheet.ciiva.com/46634/beads-commercial-power-mpz-en-46634335.pdf?src-supplier=Digikey | https://datasheet.ciiva.com/46634/beads-commercial-power-mpz-en-46634377.pdf?src-supplier=Digikey | https://datasheet.ciiva.com/46634/beads-commercial-power-mpz-en-46634377.pdf?src-supplier=Digikey | https://datasheet.ciiva.com/46634/beads-commercial-power-mpz-en-46634606.pdf?src-supplier=Digikey | https://datasheet.ciiva.com/46634/beads-commercial-power-mpz-en-46634606.pdf?src-supplier=Digikey |  |  |  |  |  |  |  |  |  |  |  |  |  |  |  |  |  |  |  |  |  |  |  |  | 228ConductorMaterial | 2A |  | 100mR
PAD_WITH_HOLE_4mmx1.5mm | PAD_WITH_HOLE_4mmx1.5mm |  |  |  |  |  |  |  |  |  |  |  |  |  | 4MMx1.5MM
QPC02SXGN-RC |  |  |  |  |  |  |  |  |  |  | Connectors |  |  |  | LINK |  |  |  |  | https://datasheet.ciiva.com/767/284-sxgn-11510-767869.pdf?src-supplier=Digikey | https://datasheet.ciiva.com/767/284-sxgn-11510-767869.pdf?src-supplier=Digikey |  |  |  |  |  |  |  |  |  |  |  |  |  |  |  |  |  |  |  |  |  | 157ConductorMaterial |  |  |  |  |  |  |  | 3A
RC0805FR-07100KL | R0805 |  |  |  |  |  |  | 0805 | 2012 | 0805 | Chip SMD Resistors |  |  |  | 100K | https://datasheet.ciiva.com/7941/1697719-7941678.pdf?src-supplier=Element14 | https://datasheet.ciiva.com/7941/1697719-7941678.pdf?src-supplier=Element14 | https://datasheet.ciiva.com/16747/rc0805-16747226.pdf?src-supplier=Future+Electronics | https://datasheet.ciiva.com/16747/rc0805-16747226.pdf?src-supplier=Future+Electronics | https://datasheet.ciiva.com/11808/0900766b8106beab-11808858.pdf?src-supplier=Rs | https://datasheet.ciiva.com/11808/0900766b8106beab-11808858.pdf?src-supplier=Rs | https://datasheet.ciiva.com/7941/1686128-7941677.pdf?src-supplier=Element14 | https://datasheet.ciiva.com/7941/1686128-7941677.pdf?src-supplier=Element14 | https://datasheet.ciiva.com/7660/38627-7660796.pdf?src-supplier=Element14 | https://datasheet.ciiva.com/7660/38627-7660796.pdf?src-supplier=Element14 | https://datasheet.ciiva.com/22747/444164-22747534.pdf?src-supplier=Element14 | https://datasheet.ciiva.com/22747/444164-22747534.pdf?src-supplier=Element14 | https://datasheet.ciiva.com/2457/pyu-r-int-thick-7-2457018.pdf?src-supplier=Digikey | https://datasheet.ciiva.com/2457/pyu-r-int-thick-7-2457018.pdf?src-supplier=Digikey | https://datasheet.ciiva.com/2457/pyu-r-int-thick-7-2457019.pdf?src-supplier=Digikey | https://datasheet.ciiva.com/2457/pyu-r-int-thick-7-2457019.pdf?src-supplier=Digikey | https://datasheet.ciiva.com/2457/pyu-r-int-thick-7-2457017.pdf?src-supplier=Digikey | https://datasheet.ciiva.com/2457/pyu-r-int-thick-7-2457017.pdf?src-supplier=Digikey | https://datasheet.ciiva.com/12667/rc0805-12667001.pdf?src-supplier=Mouser | https://datasheet.ciiva.com/12667/rc0805-12667001.pdf?src-supplier=Mouser | https://datasheet.ciiva.com/7941/1697719-7941676.pdf?src-supplier=Element14 | https://datasheet.ciiva.com/7941/1697719-7941676.pdf?src-supplier=Element14 |  | Rectangular |  |  |  |  |  |  |  |  |  |  |  |  |  |  | 1.25mm
RC0805FR-0710KL | R0805 |  |  |  |  |  |  | 0805 | 2012 | 0805 | Chip SMD Resistors |  |  |  | 10k |  |  |  |  |  |  |  |  |  |  |  |  |  |  |  |  |  |  |  |  |  |  |  | Rectangular |  |  |  |  |  |  |  |  |  |  |  |  |  |  | 1.25mm
RC0805FR-071KL | R0805 |  |  |  |  |  |  | 0805 | 2012 | 0805 | Chip SMD Resistors |  |  |  | 1K |  |  |  |  | https://datasheet.ciiva.com/7941/1686128-7941719.pdf?src-supplier=Element14 | https://datasheet.ciiva.com/7941/1686128-7941719.pdf?src-supplier=Element14 | https://datasheet.ciiva.com/46385/444164-46385020.pdf?src-supplier=Element14 | https://datasheet.ciiva.com/46385/444164-46385020.pdf?src-supplier=Element14 | https://datasheet.ciiva.com/2456/pyu-r-int-thick-7-2456976.pdf?src-supplier=Digikey | https://datasheet.ciiva.com/2456/pyu-r-int-thick-7-2456976.pdf?src-supplier=Digikey | https://datasheet.ciiva.com/2456/pyu-r-int-thick-7-2456977.pdf?src-supplier=Digikey | https://datasheet.ciiva.com/2456/pyu-r-int-thick-7-2456977.pdf?src-supplier=Digikey | https://datasheet.ciiva.com/2456/pyu-r-int-thick-7-2456975.pdf?src-supplier=Digikey | https://datasheet.ciiva.com/2456/pyu-r-int-thick-7-2456975.pdf?src-supplier=Digikey | https://datasheet.ciiva.com/16850/rc0805-16850409.pdf?src-supplier=Future+Electronics | https://datasheet.ciiva.com/16850/rc0805-16850409.pdf?src-supplier=Future+Electronics |  |  |  |  |  |  |  | Rectangular |  |  |  |  |  |  |  |  |  |  |  |  |  |  | 1.25mm
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

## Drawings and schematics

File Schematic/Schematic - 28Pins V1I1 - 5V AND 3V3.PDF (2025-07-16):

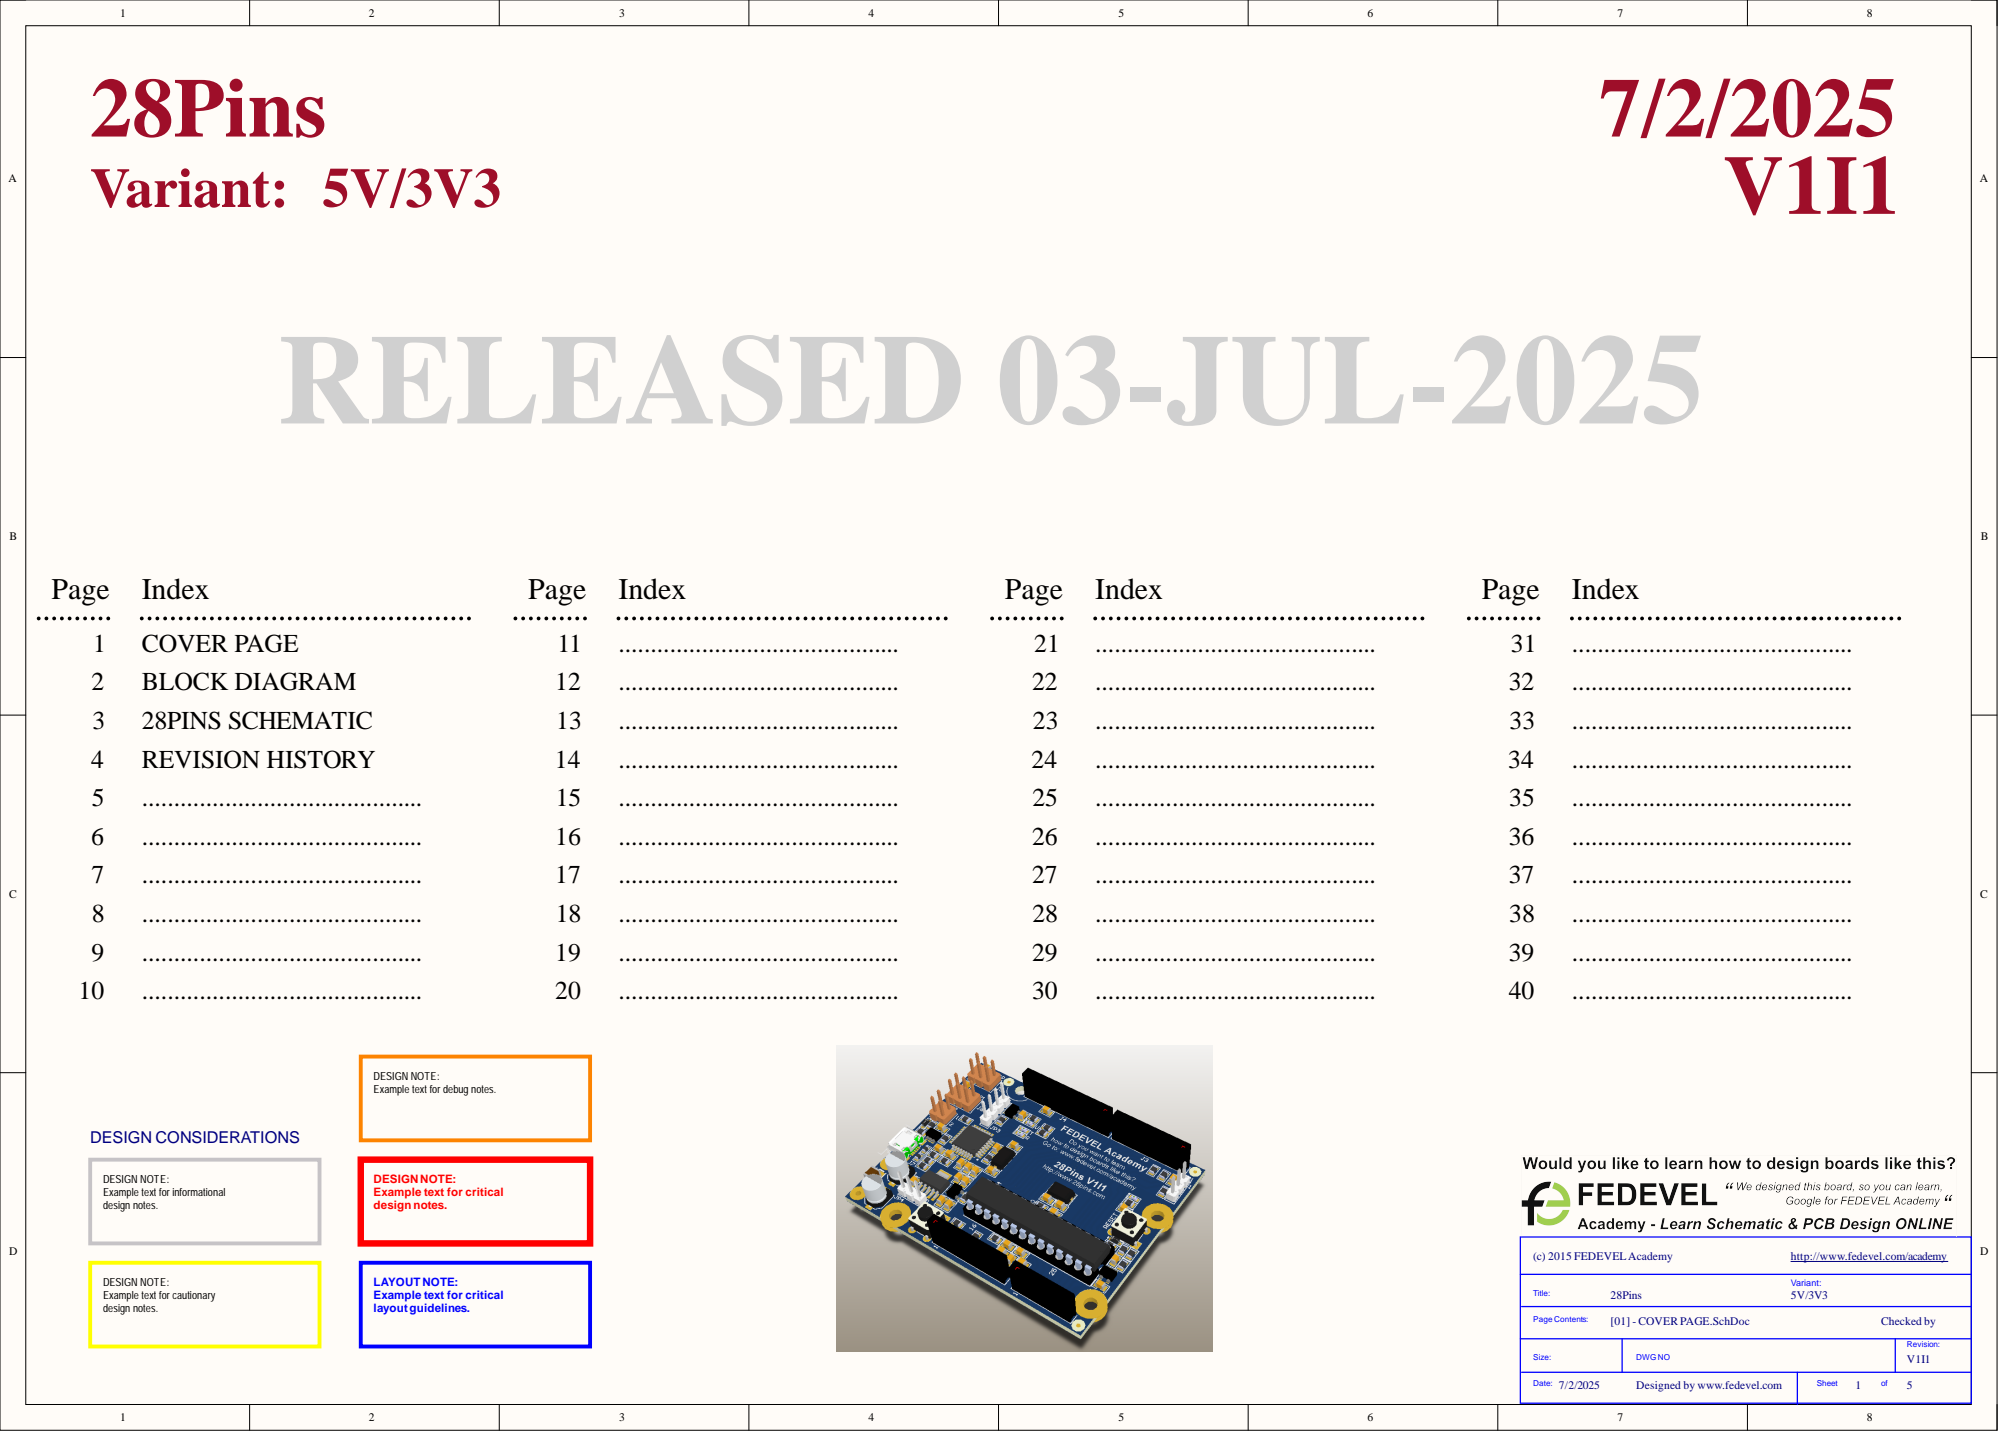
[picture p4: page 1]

DESIGN NOTE:
Example text for debug notes.

Example text for informational
design notes.

Example text for critical

http://www.fedevel.com/academy

Example text for cautionary

LAYOUT NOTE:
layout guidelines.

Size: | DWG NO | Revision: V1I1

Date: 7/2/2025 Designed by www.fedevel.com | Sheet of

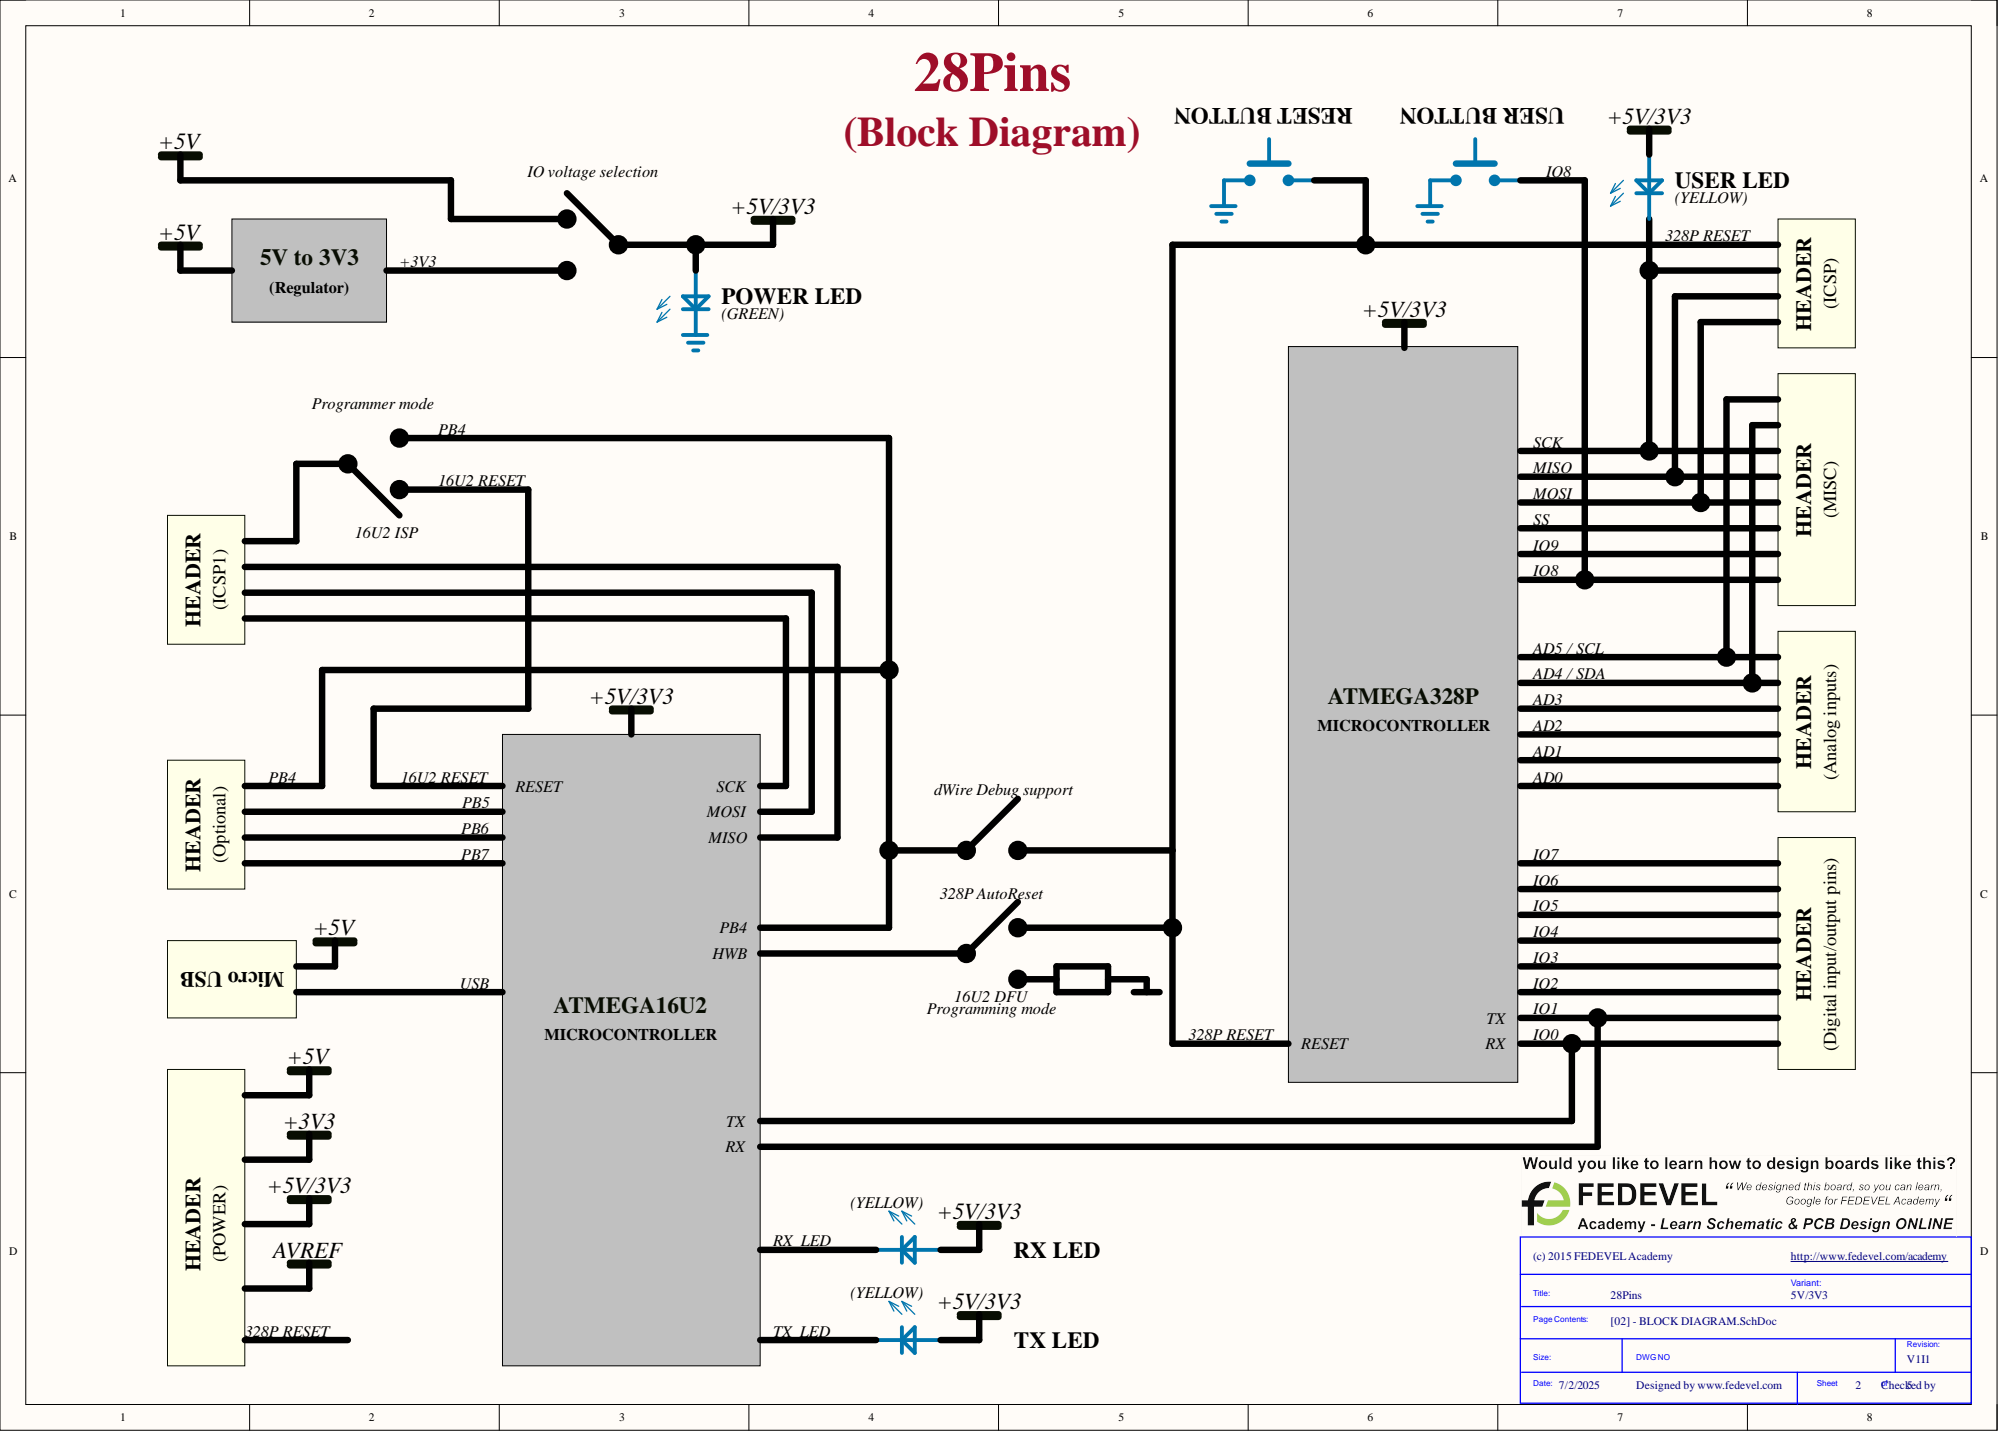
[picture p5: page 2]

MISO
MOSI
SS
IO9
IO8

AD5 / SCL
AD4 / SDA

http://www.fedevel.com/academy

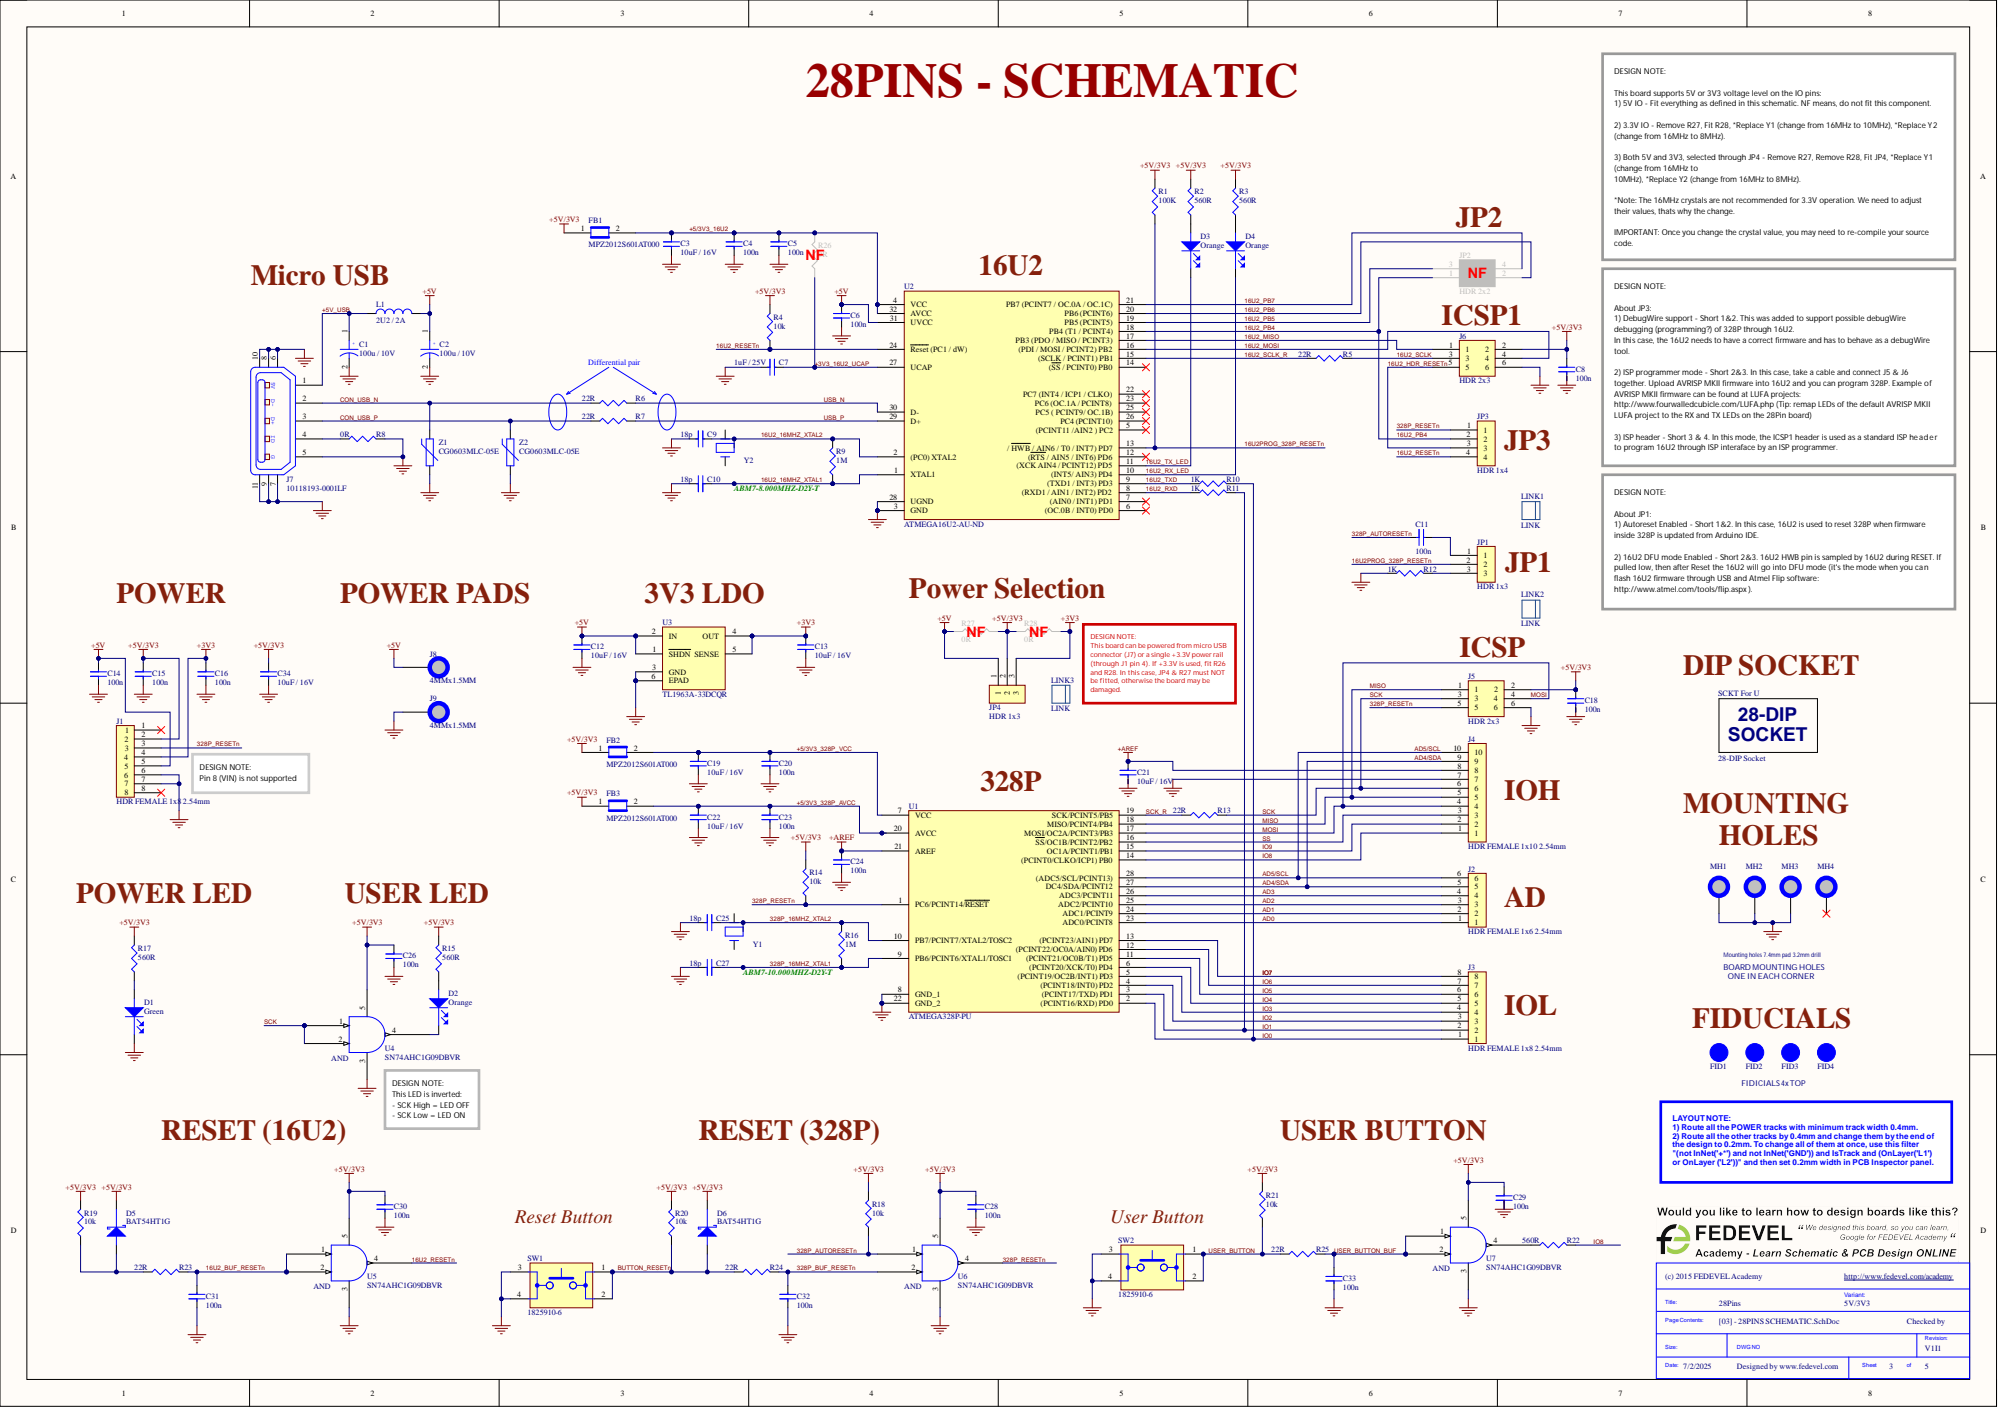
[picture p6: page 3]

This board supports 5V or 3V3 voltage level on the IO pins:
1) 5V IO - Fit everything as defined in this schematic. NF means, do not fit this component.

2) 3.3V IO - Remove R27, Fit R28, *Replace Y1 (change from 16MHz to 10MHz), *Replace Y2
(change from 16MHz to 8MHz).

3) Both 5V and 3V3, selected through JP4 - Remove R27, Remove R28, Fit JP4, *Replace Y1
(change from 16MHz to
10MHz), *Replace Y2 (change from 16MHz to 8MHz).

*Note: The 16MHz crystals are not recommended for 3.3V operation. We need to adjust
their values, thats why the change.

IMPORTANT: Once you change the crystal value, you may need to re-compile your source
code.

C6 | | 16U2_PB6 | ICSP1

About JP3:
1) DebugWire support - Short 1&2. This was added to support possible debugWire
debugging (programming?) of 328P through 16U2.
In this case, the 16U2 needs to have a correct firmware and has to behave as a debugWire
tool.

Reset (PC1 / dW) 24 | | 16U2_PB4

16U2_MISO | | J6

2) ISP programmer mode - Short 2&3. In this case, take a cable and connect J5 & J6
together. Upload AVRISP MKII firmware into 16U2 and you can program 328P. Example of
AVRISP MKII firmware can be found at LUFA projects:
http://www.fourwalledcubicle.com/LUFA.php (Tip: remap LEDs of the default AVRISP MKII
LUFA project to the RX and TX LEDs on the 28Pin board)

3) ISP header - Short 3 & 4. In this mode, the ICSP1 header is used as a standard ISP header
to program 16U2 through ISP interaface by an ISP programmer.

About JP1:
1) Autoreset Enabled - Short 1&2. In this case, 16U2 is used to reset 328P when firmware
inside 328P is updated from Arduino IDE.

2) 16U2 DFU mode Enabled - Short 2&3. 16U2 HWB pin is sampled by 16U2 during RESET. If
pulled low, then after Reset the 16U2 will go into DFU mode (it's the mode when you can
flash 16U2 firmware through USB and Atmel Flip software:
http://www.atmel.com/tools/flip.aspx ).

DESIGN NOTE:
This board can be powered from micro USB
connector (J7) or a single +3.3V power rail
(through J1 pin 4). If +3.3V is used, fit R26
and R28. In this case, JP4 & R27 must NOT
be fitted, otherwise the board may be
damaged.

Pin 8 (VIN) is not supported

SCK_R 22R R13 | SCK

MISO

AREF 21 | | SS

PC6/PCINT14/RESET 1 | | IO8

AD5/SCL

PB7/PCINT7/XTAL2/TOSC2 10 | | AD1

Mounting holes 7.4mm pad 3.2mm drill
BOARD MOUNTING HOLES
ONE IN EACH CORNER
FIDUCIALS

GND_2 22 | IO4

IO3
IO2
IO1
IO0

This LED is inverted:
- SCK High = LED OFF
- SCK Low = LED ON

LAYOUT NOTE:
1) Route all the POWER tracks with minimum track width 0.4mm.
2) Route all the other tracks by 0.4mm and change them by the end of
the design to 0.2mm. To change all of them at once, use this filter
"(not InNet('+*') and not InNet('GND')) and IsTrack and (OnLayer('L1')
or OnLayer ('L2'))" and then set 0.2mm width in PCB Inspector panel.

http://www.fedevel.com/academy

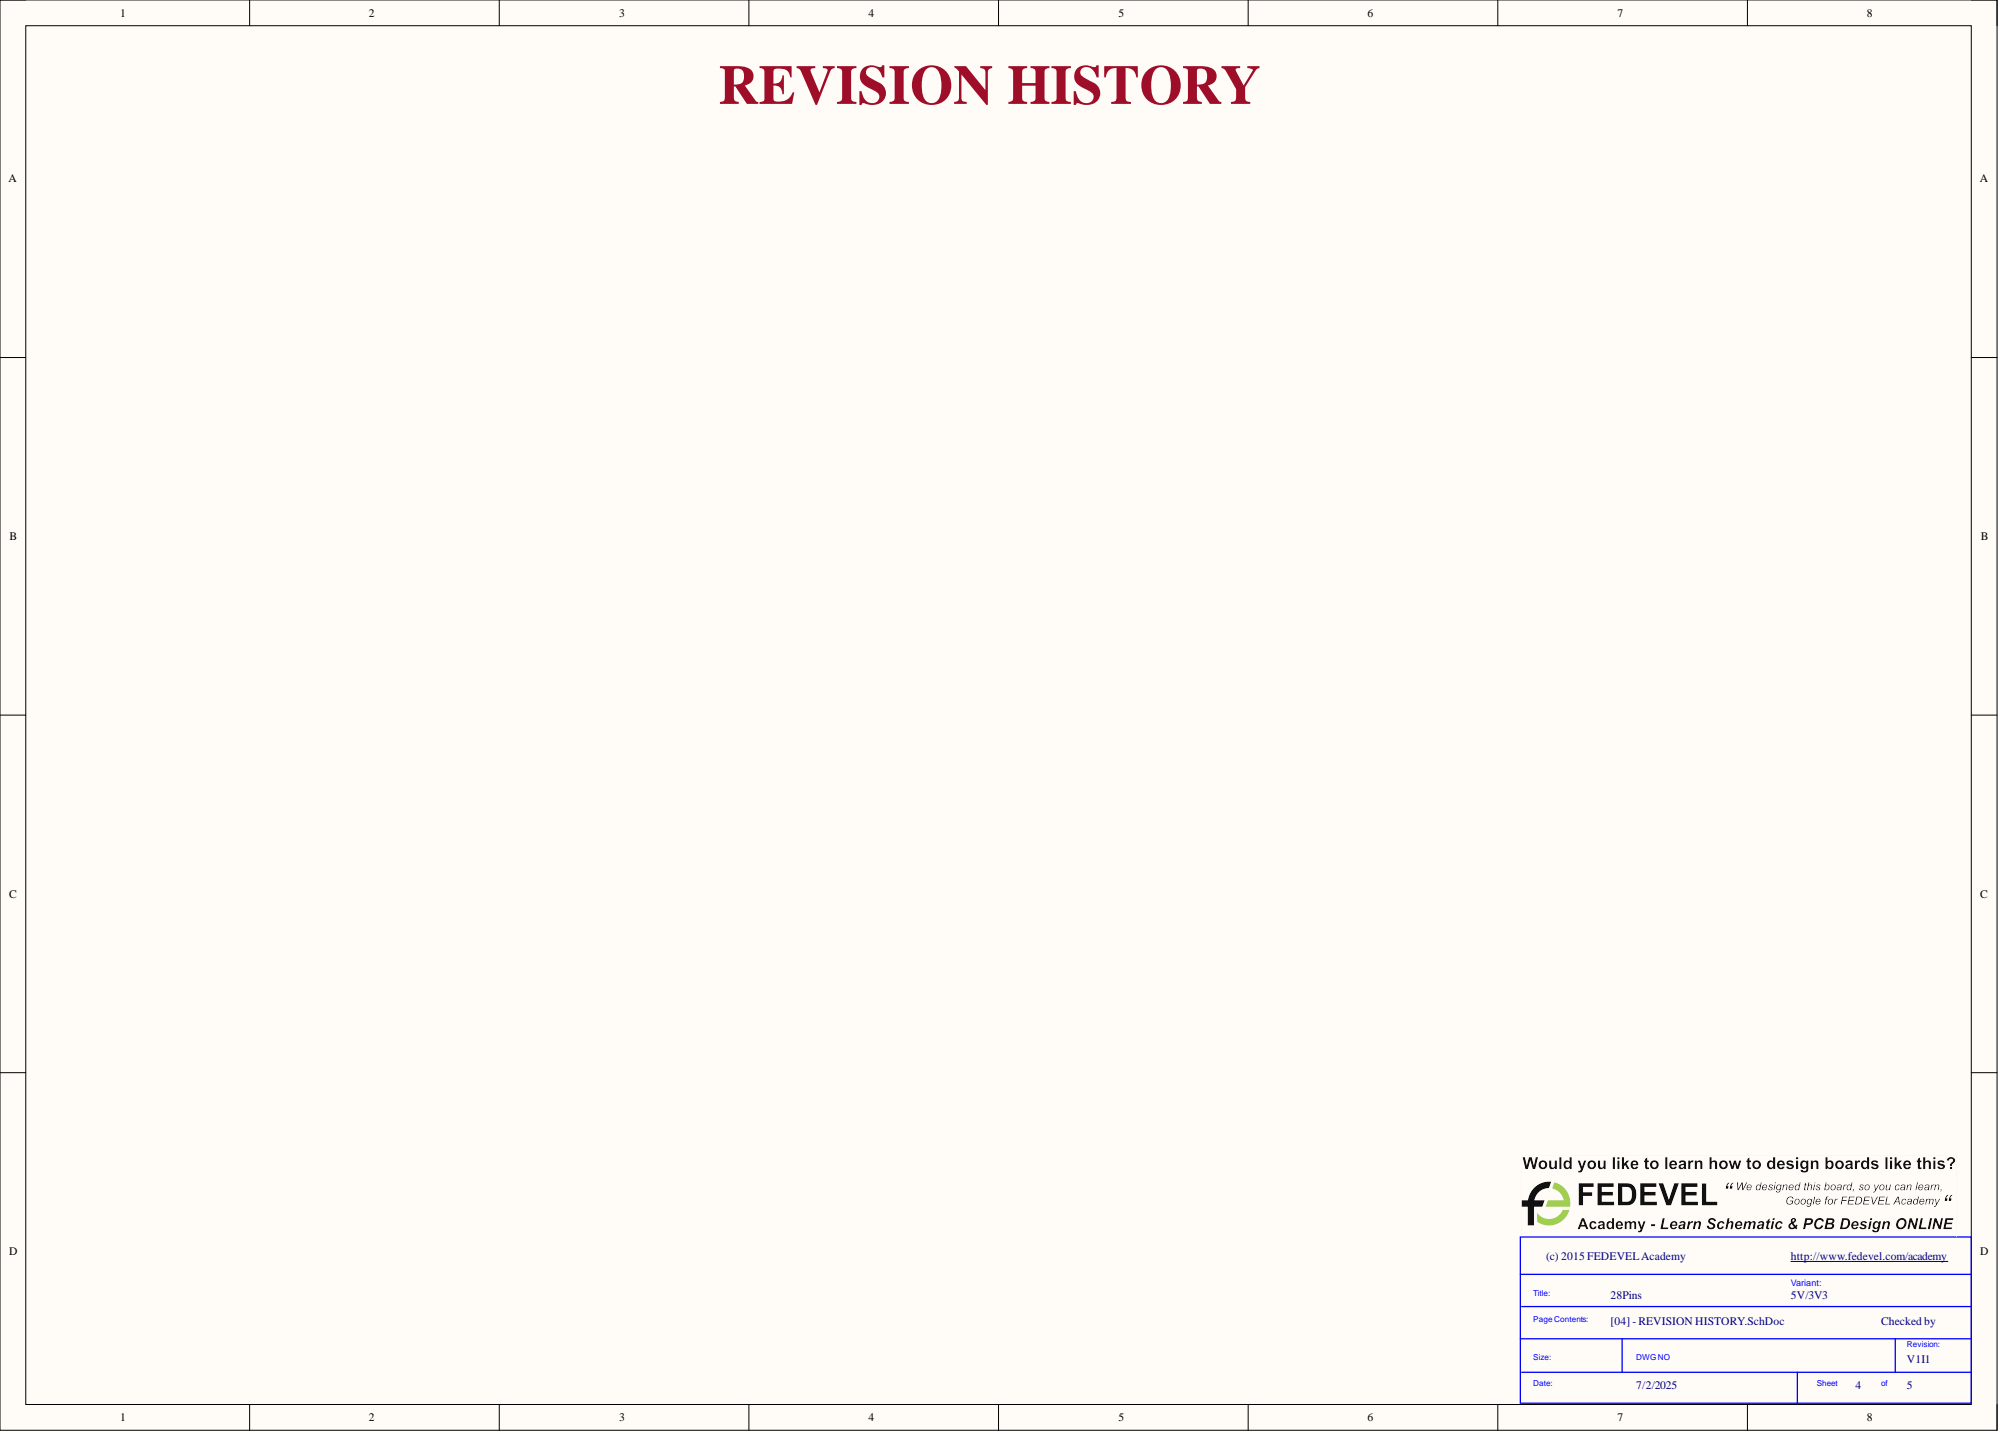
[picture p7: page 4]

http://www.fedevel.com/academy

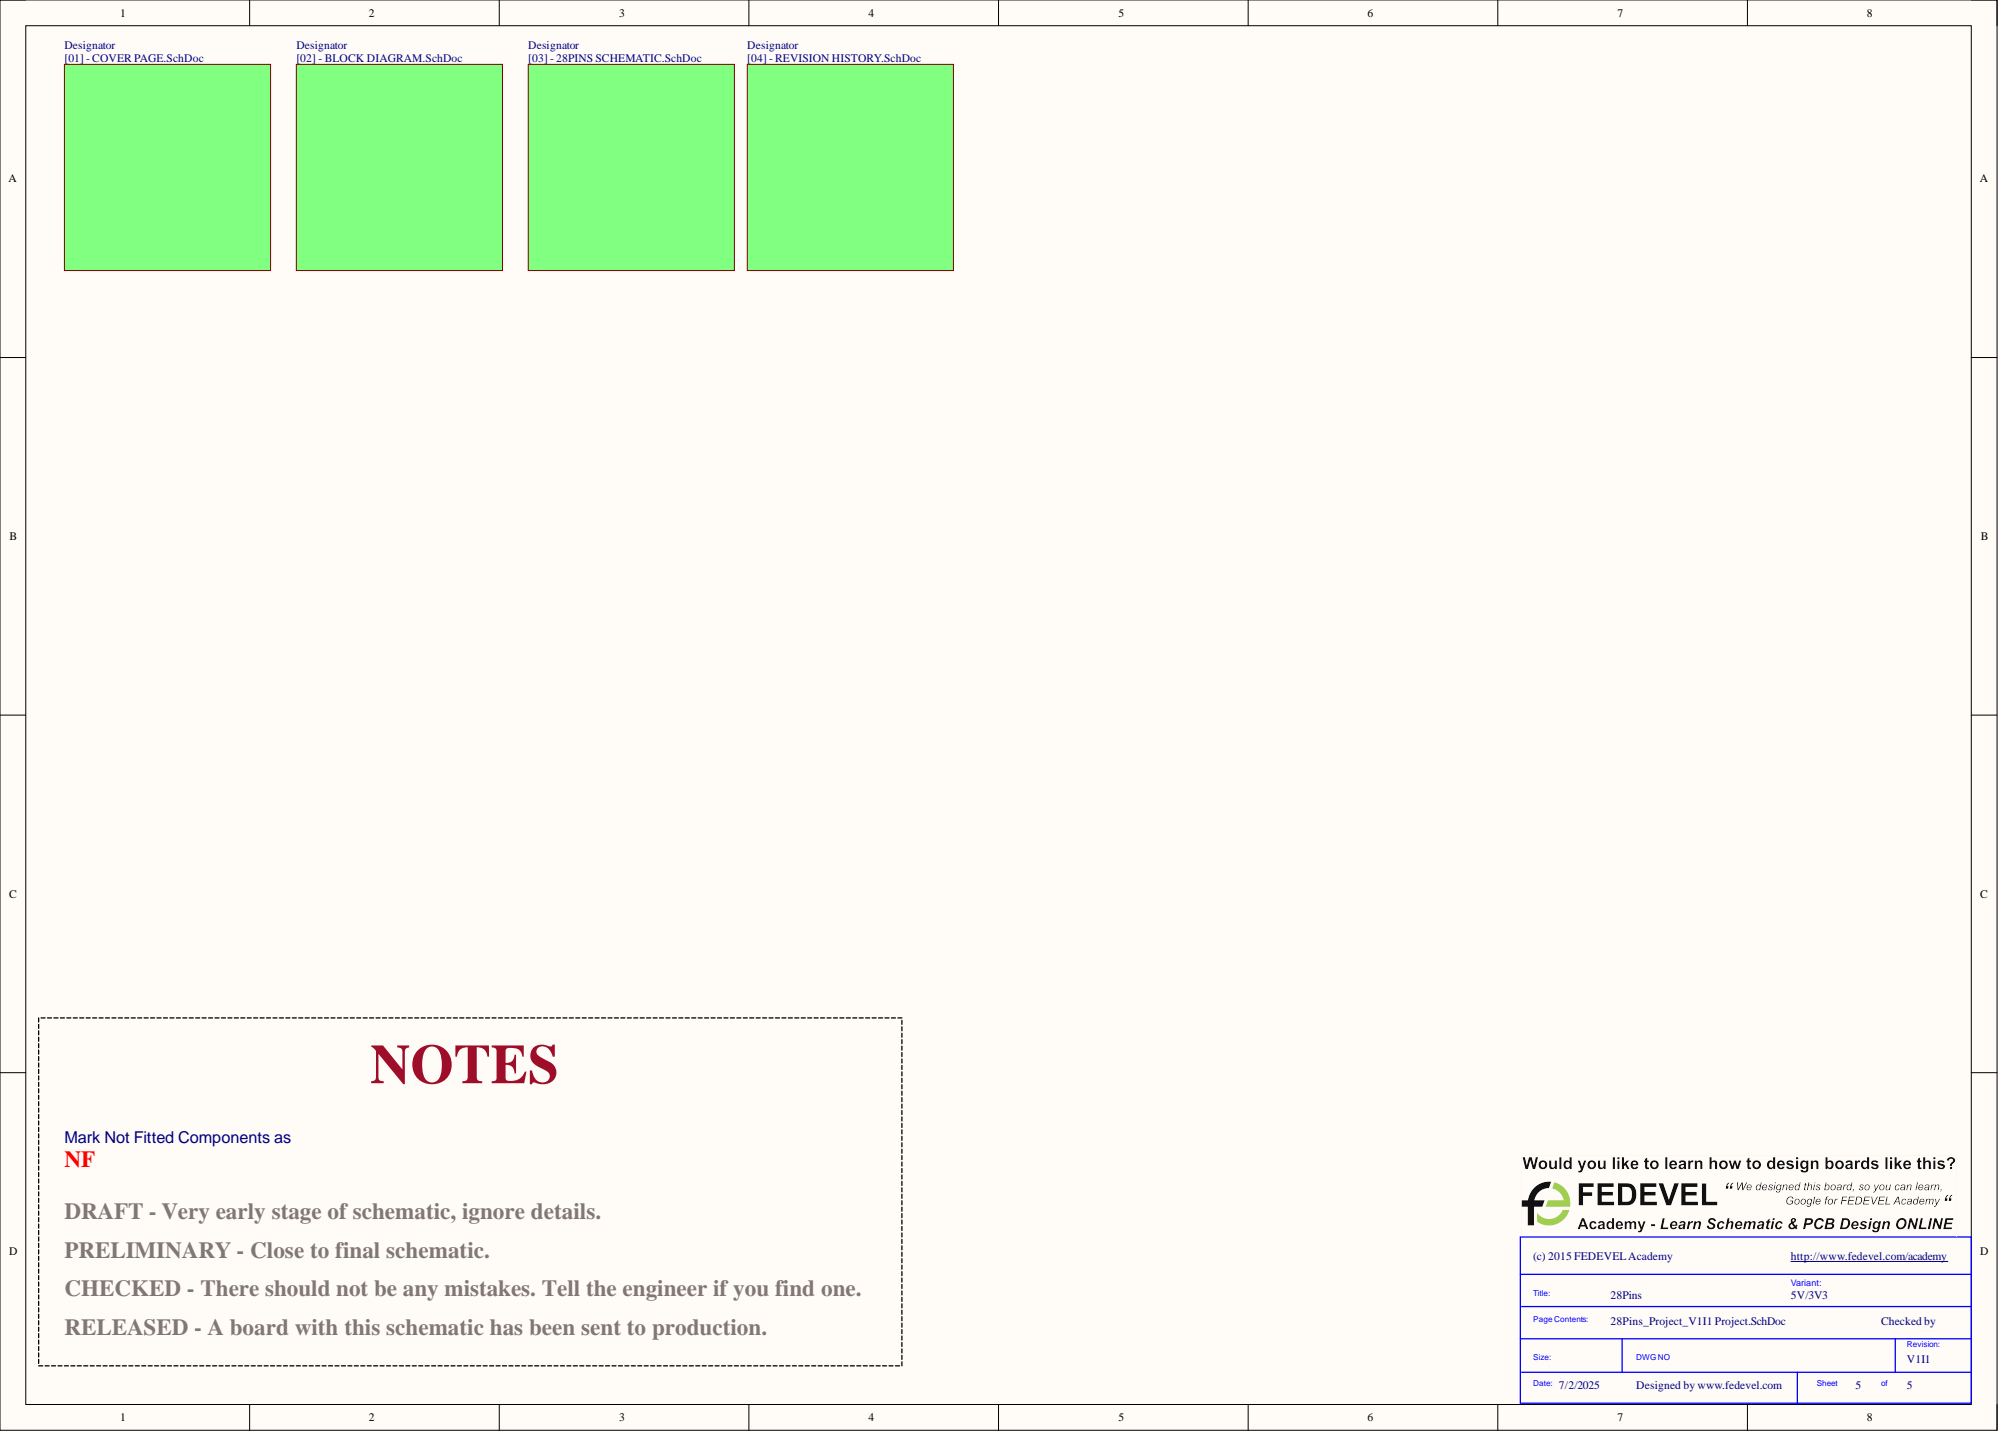
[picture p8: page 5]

Mark Not Fitted Components as

DRAFT - Very early stage of schematic, ignore details.
PRELIMINARY - Close to final schematic.
CHECKED - There should not be any mistakes. Tell the engineer if you find one.
RELEASED - A board with this schematic has been sent to production.

http://www.fedevel.com/academy

Designed by www.fedevel.com

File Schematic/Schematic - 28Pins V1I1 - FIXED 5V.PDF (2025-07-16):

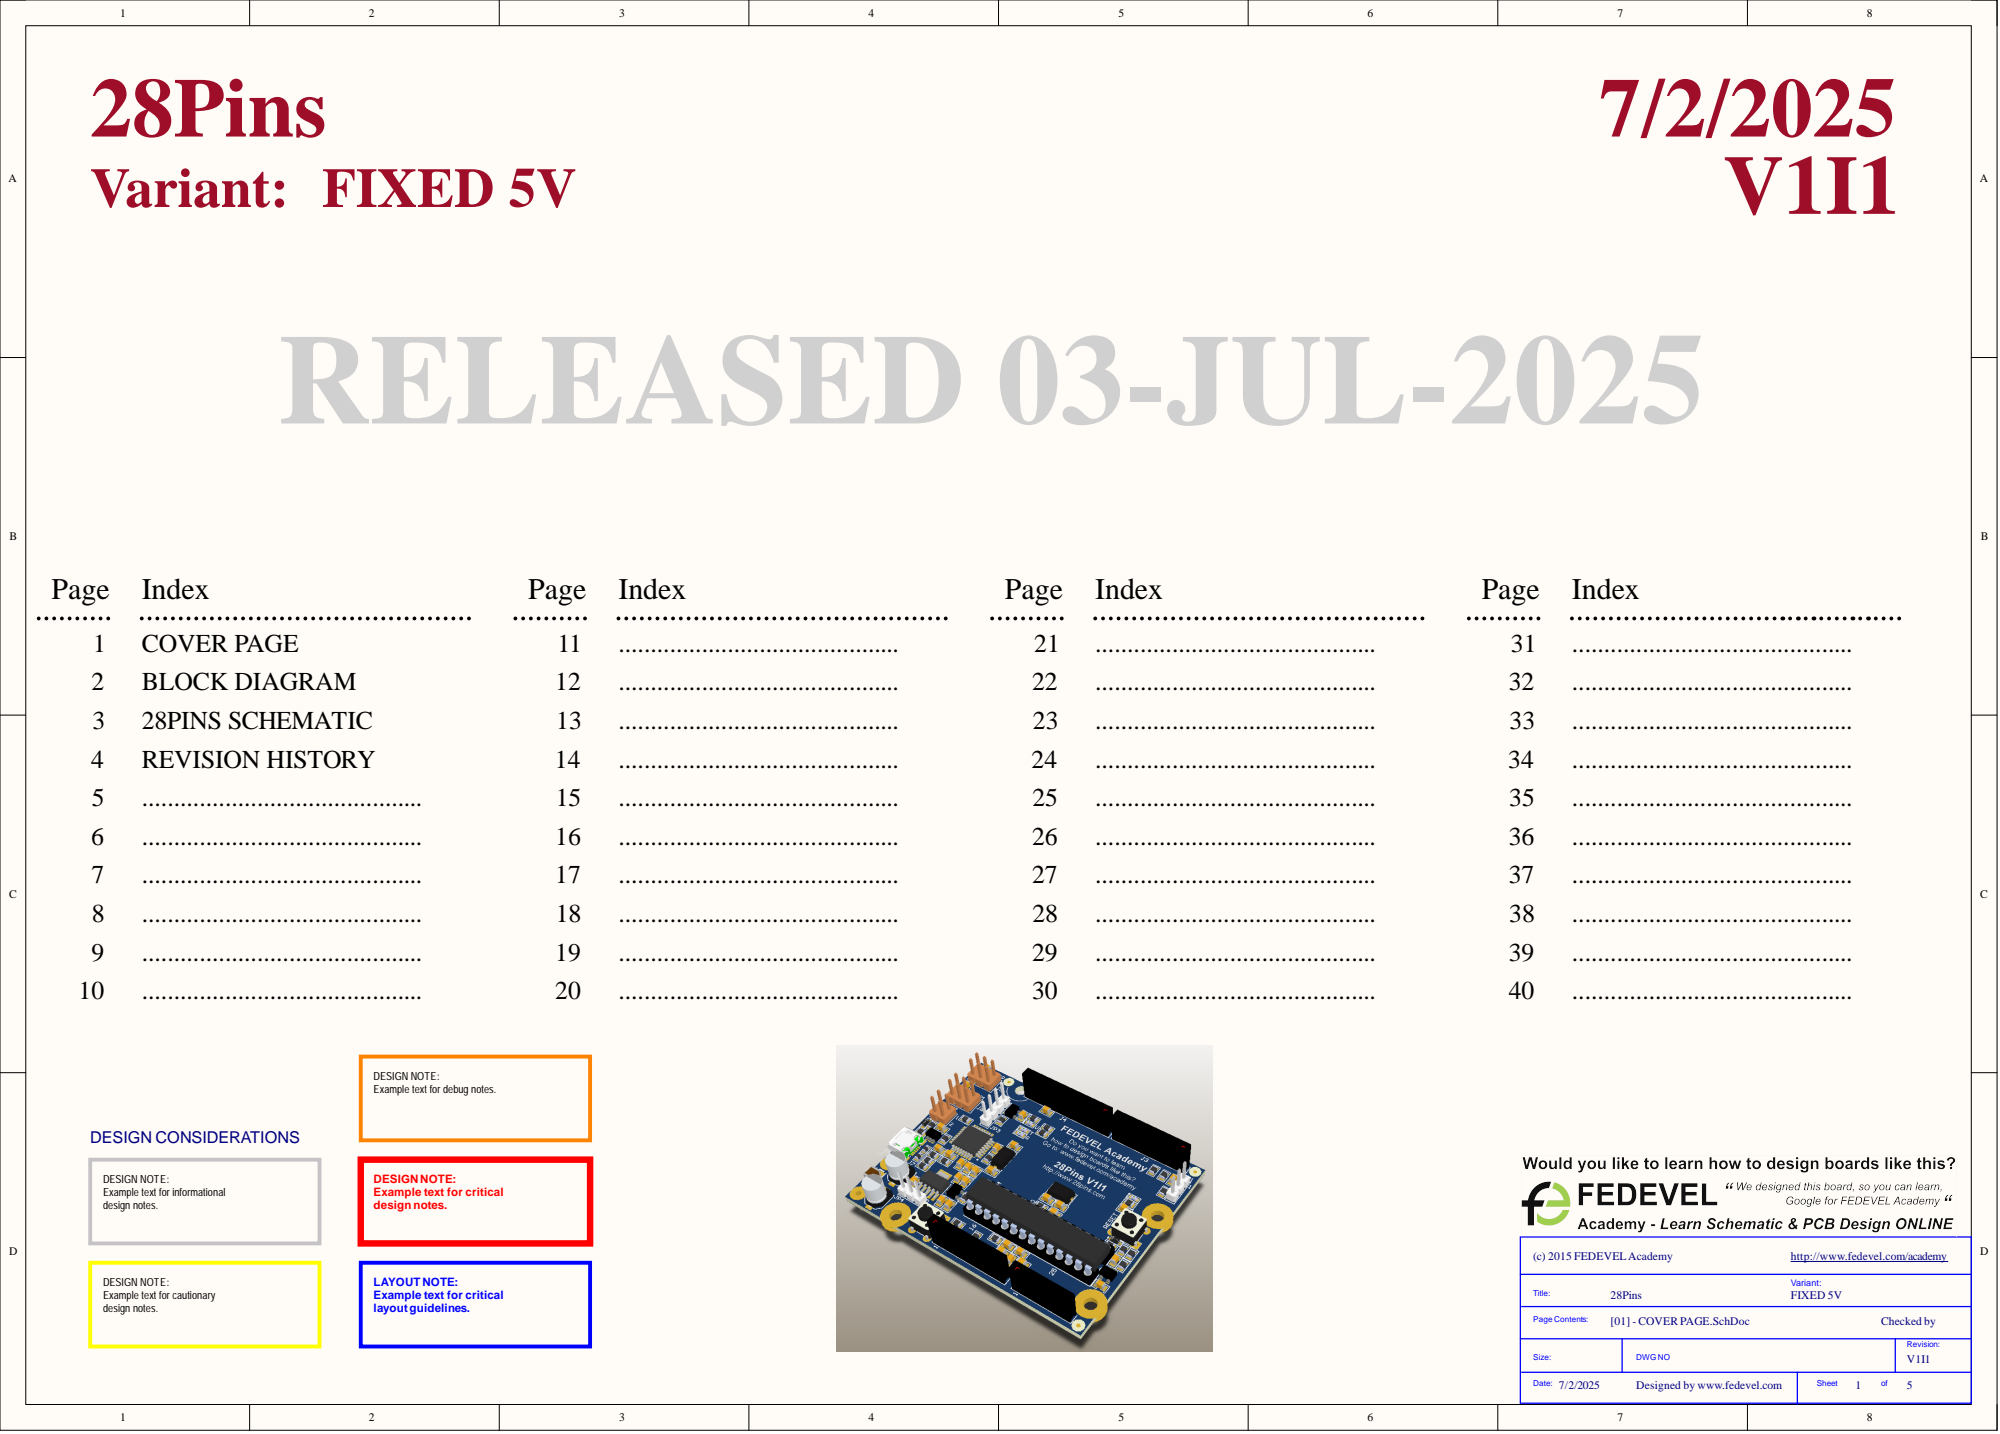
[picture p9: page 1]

DESIGN NOTE:
Example text for debug notes.

Example text for informational
design notes.

Example text for critical

http://www.fedevel.com/academy

Example text for cautionary

LAYOUT NOTE:
layout guidelines.

Size: | DWG NO | Revision: V1I1

Date: 7/2/2025 Designed by www.fedevel.com | Sheet of

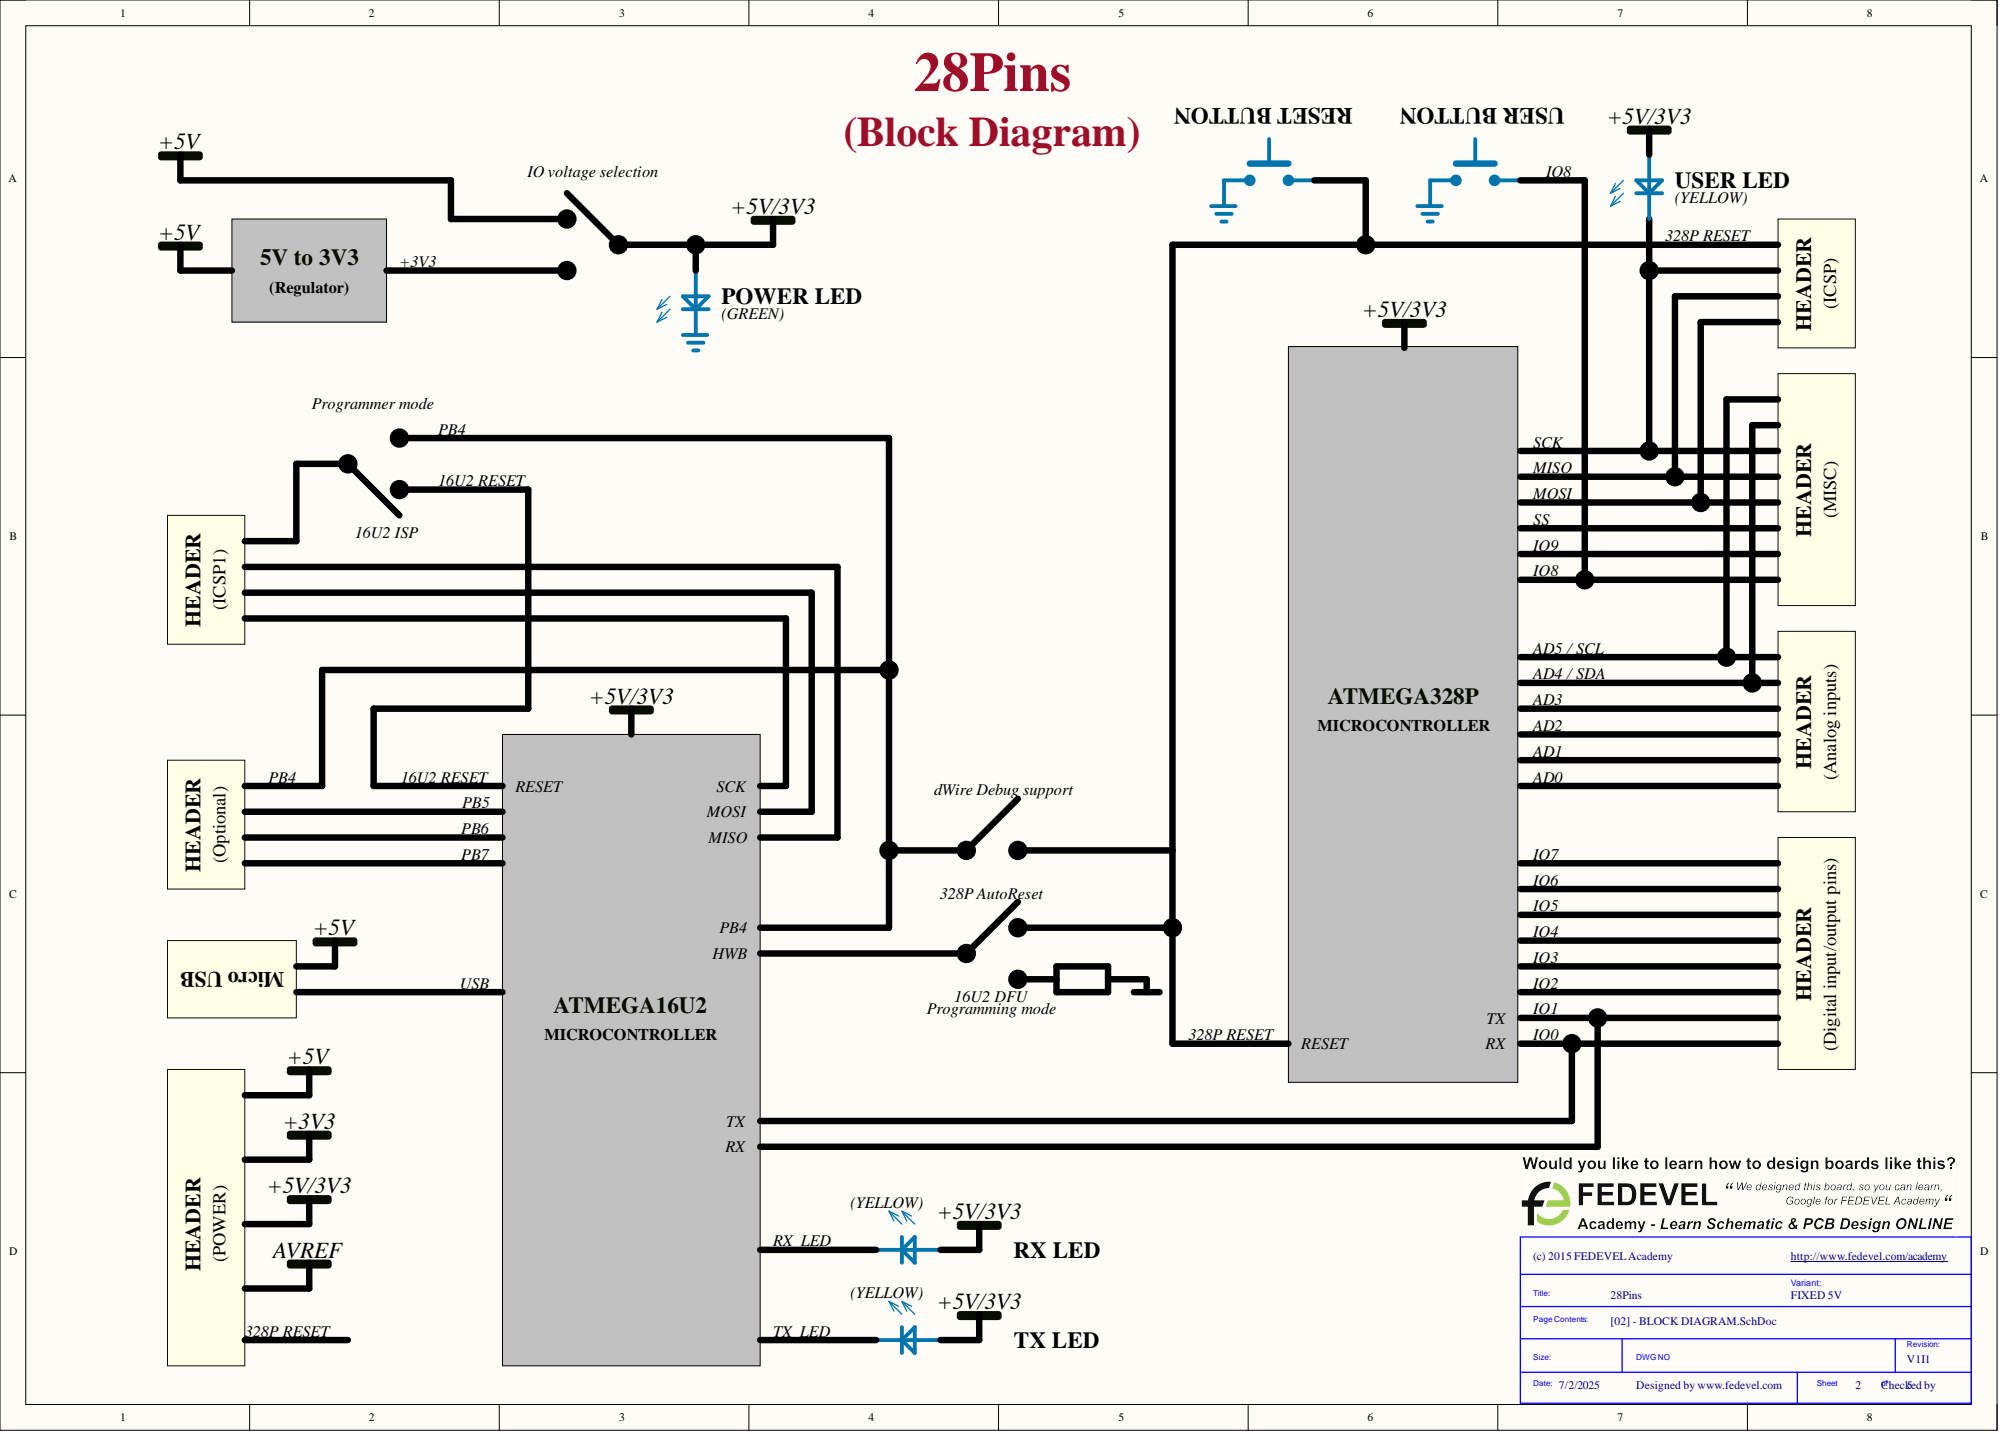
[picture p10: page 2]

MISO
MOSI
SS
IO9
IO8

AD5 / SCL
AD4 / SDA

http://www.fedevel.com/academy

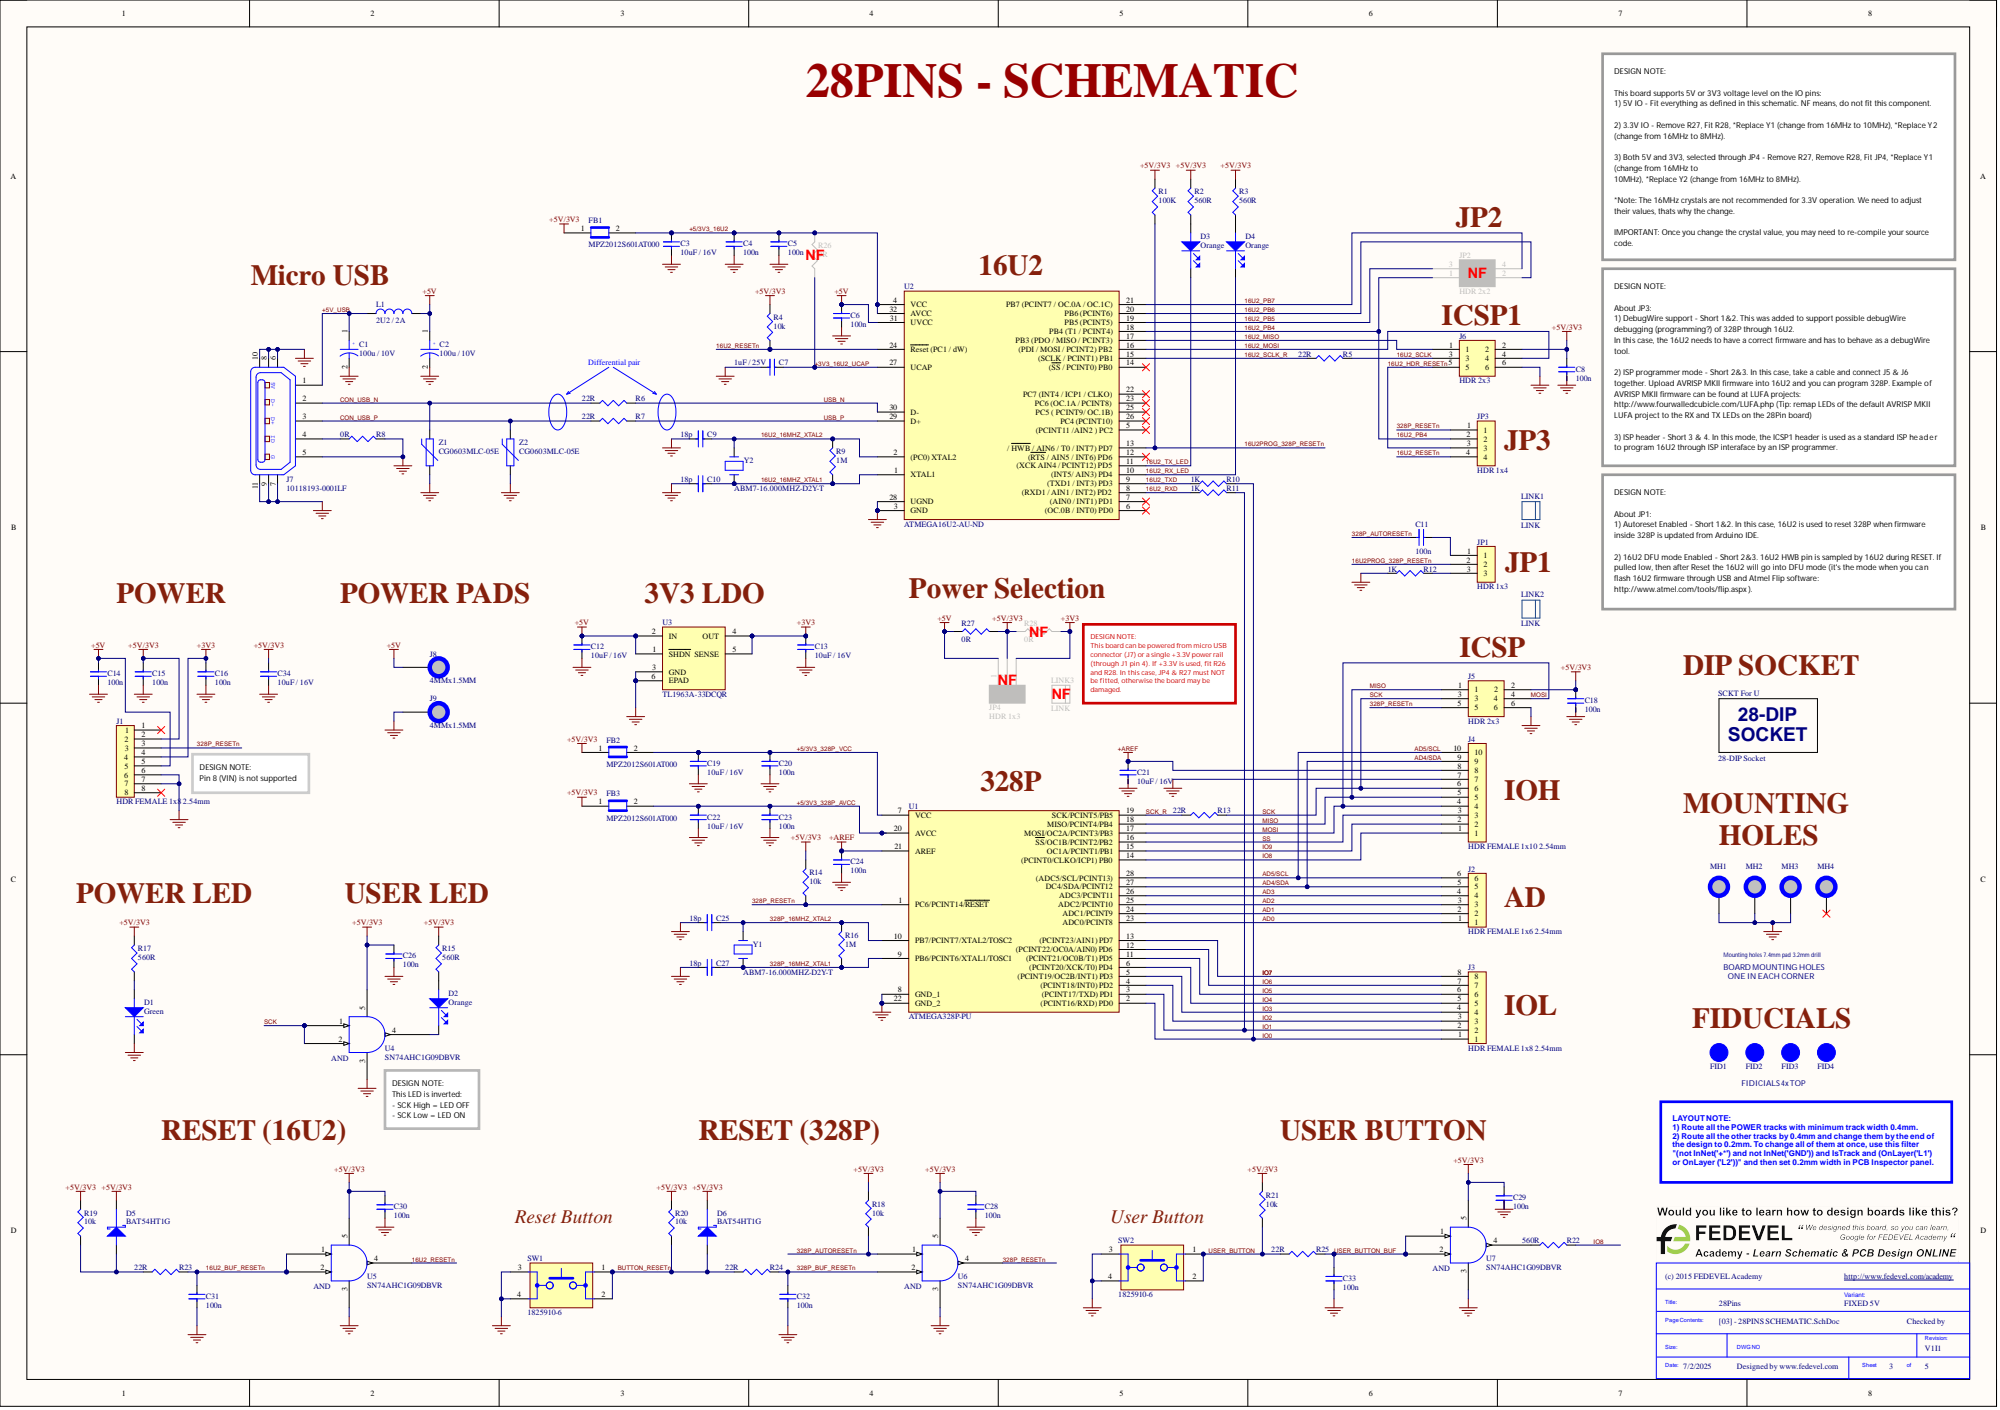
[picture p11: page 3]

This board supports 5V or 3V3 voltage level on the IO pins:
1) 5V IO - Fit everything as defined in this schematic. NF means, do not fit this component.

2) 3.3V IO - Remove R27, Fit R28, *Replace Y1 (change from 16MHz to 10MHz), *Replace Y2
(change from 16MHz to 8MHz).

3) Both 5V and 3V3, selected through JP4 - Remove R27, Remove R28, Fit JP4, *Replace Y1
(change from 16MHz to
10MHz), *Replace Y2 (change from 16MHz to 8MHz).

*Note: The 16MHz crystals are not recommended for 3.3V operation. We need to adjust
their values, thats why the change.

IMPORTANT: Once you change the crystal value, you may need to re-compile your source
code.

C6 | | 16U2_PB6 | ICSP1

About JP3:
1) DebugWire support - Short 1&2. This was added to support possible debugWire
debugging (programming?) of 328P through 16U2.
In this case, the 16U2 needs to have a correct firmware and has to behave as a debugWire
tool.

Reset (PC1 / dW) 24 UCAP 27 | | 16U2_PB4

16U2_MISO | | J6

2) ISP programmer mode - Short 2&3. In this case, take a cable and connect J5 & J6
together. Upload AVRISP MKII firmware into 16U2 and you can program 328P. Example of
AVRISP MKII firmware can be found at LUFA projects:
http://www.fourwalledcubicle.com/LUFA.php (Tip: remap LEDs of the default AVRISP MKII
LUFA project to the RX and TX LEDs on the 28Pin board)

3) ISP header - Short 3 & 4. In this mode, the ICSP1 header is used as a standard ISP header
to program 16U2 through ISP interaface by an ISP programmer.

About JP1:
1) Autoreset Enabled - Short 1&2. In this case, 16U2 is used to reset 328P when firmware
inside 328P is updated from Arduino IDE.

2) 16U2 DFU mode Enabled - Short 2&3. 16U2 HWB pin is sampled by 16U2 during RESET. If
pulled low, then after Reset the 16U2 will go into DFU mode (it's the mode when you can
flash 16U2 firmware through USB and Atmel Flip software:
http://www.atmel.com/tools/flip.aspx ).

DESIGN NOTE:
This board can be powered from micro USB
connector (J7) or a single +3.3V power rail
(through J1 pin 4). If +3.3V is used, fit R26
and R28. In this case, JP4 & R27 must NOT
be fitted, otherwise the board may be
damaged.

Pin 8 (VIN) is not supported

SCK_R 22R R13 | SCK

MISO

AREF 21 | | SS

PC6/PCINT14/RESET 1 | | IO8

AD5/SCL

PB7/PCINT7/XTAL2/TOSC2 10 | | AD1

Mounting holes 7.4mm pad 3.2mm drill
BOARD MOUNTING HOLES
ONE IN EACH CORNER
FIDUCIALS

GND_2 22 | IO4

IO3
IO2
IO1
IO0

This LED is inverted:
- SCK High = LED OFF
- SCK Low = LED ON

LAYOUT NOTE:
1) Route all the POWER tracks with minimum track width 0.4mm.
2) Route all the other tracks by 0.4mm and change them by the end of
the design to 0.2mm. To change all of them at once, use this filter
"(not InNet('+*') and not InNet('GND')) and IsTrack and (OnLayer('L1')
or OnLayer ('L2'))" and then set 0.2mm width in PCB Inspector panel.

http://www.fedevel.com/academy

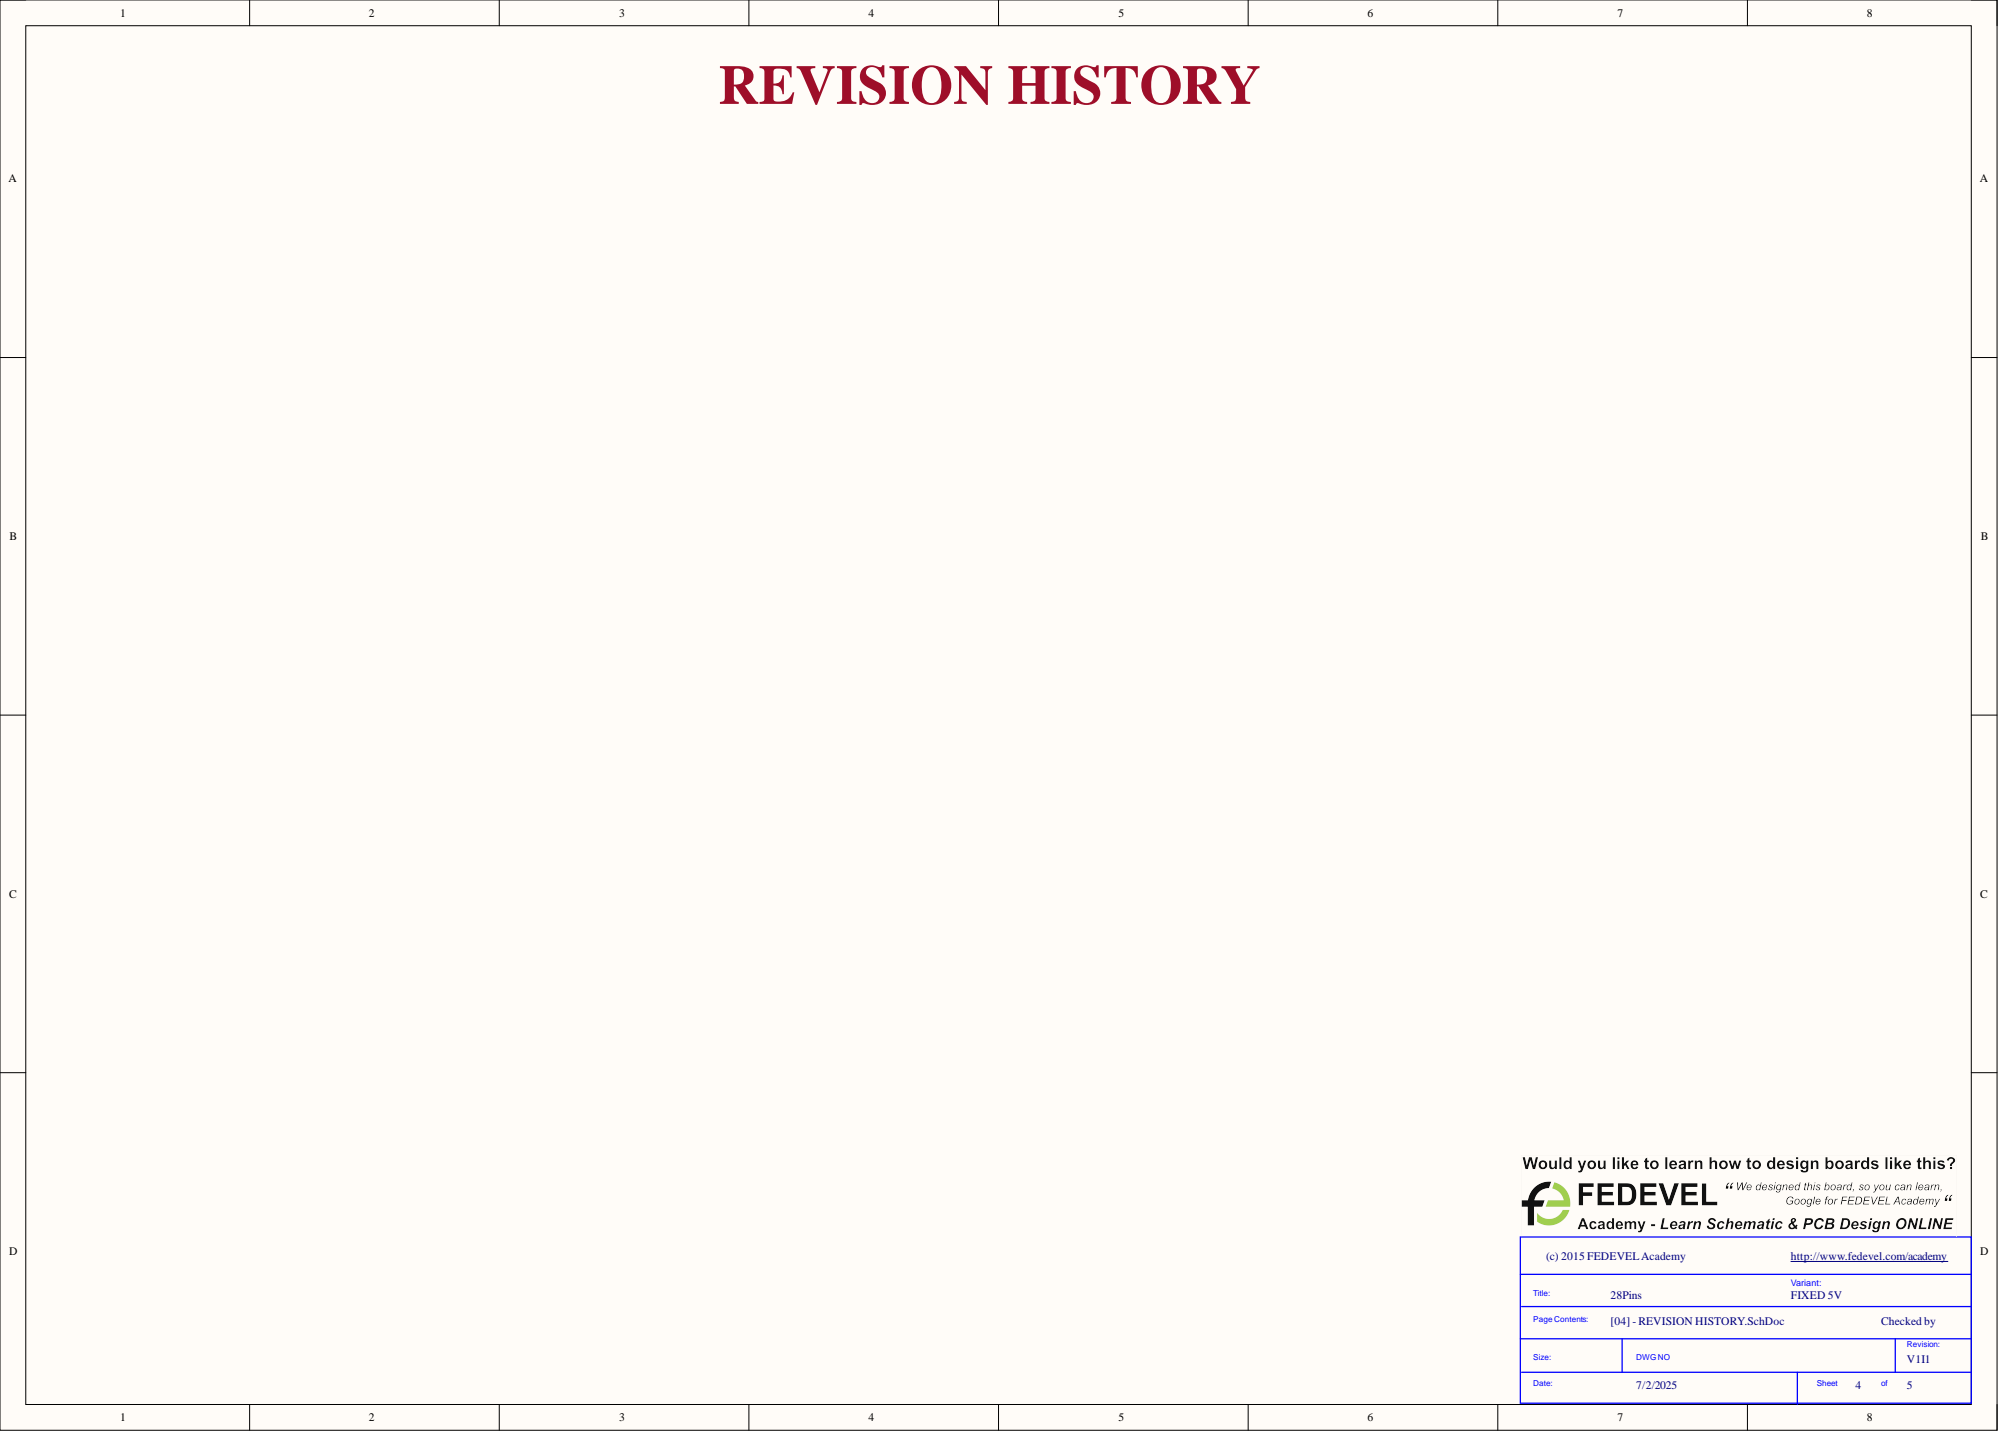
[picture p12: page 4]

http://www.fedevel.com/academy

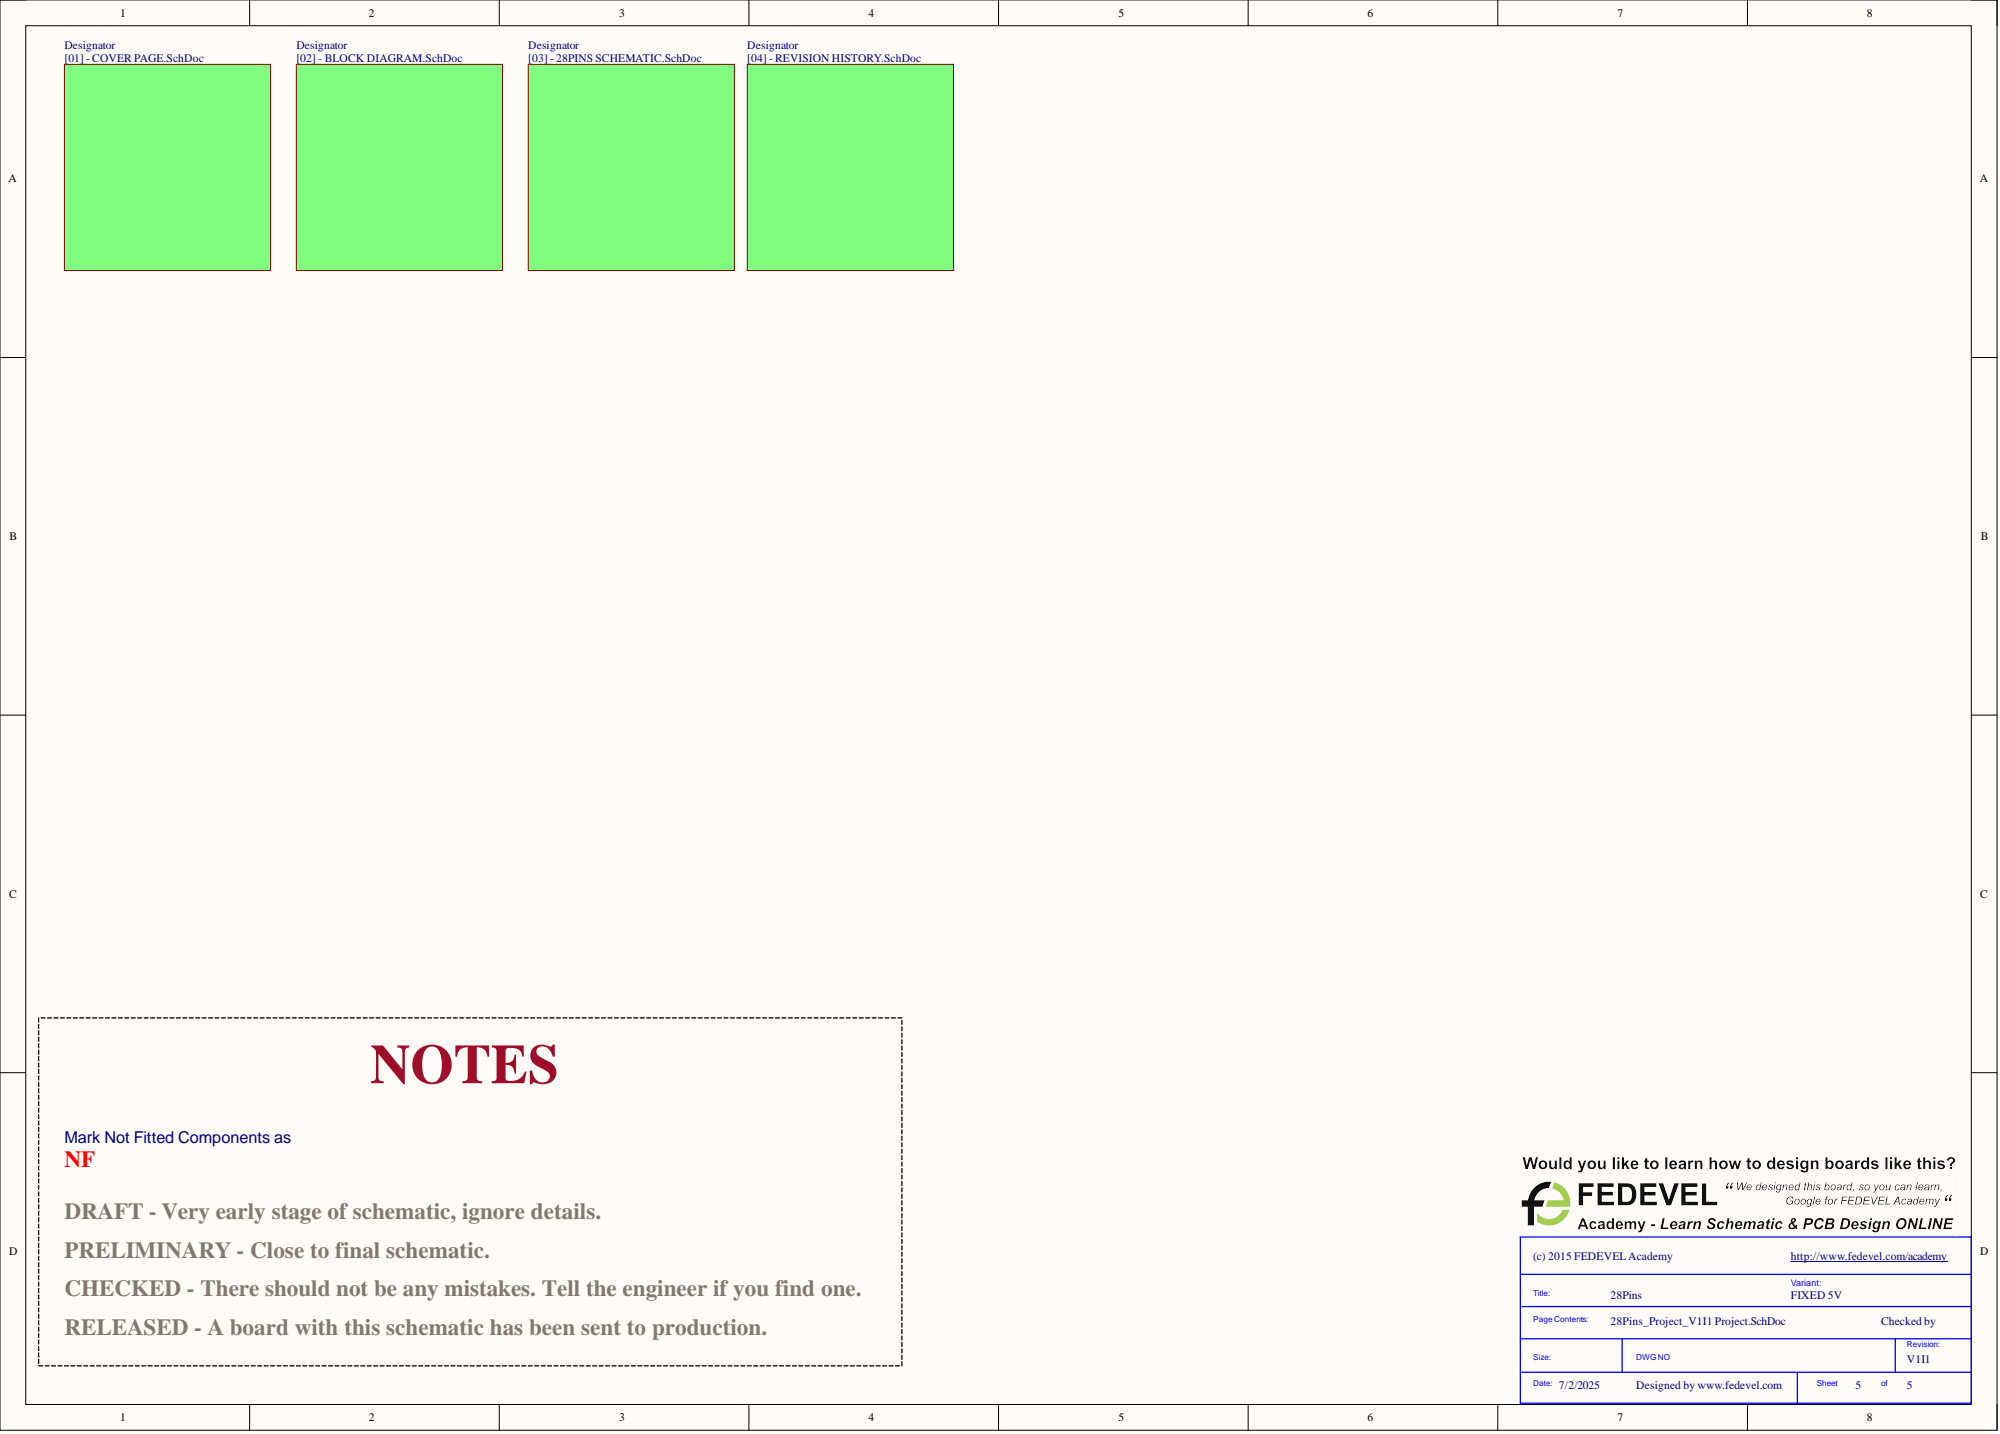
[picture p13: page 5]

Mark Not Fitted Components as

DRAFT - Very early stage of schematic, ignore details.
PRELIMINARY - Close to final schematic.
CHECKED - There should not be any mistakes. Tell the engineer if you find one.
RELEASED - A board with this schematic has been sent to production.

http://www.fedevel.com/academy

Designed by www.fedevel.com

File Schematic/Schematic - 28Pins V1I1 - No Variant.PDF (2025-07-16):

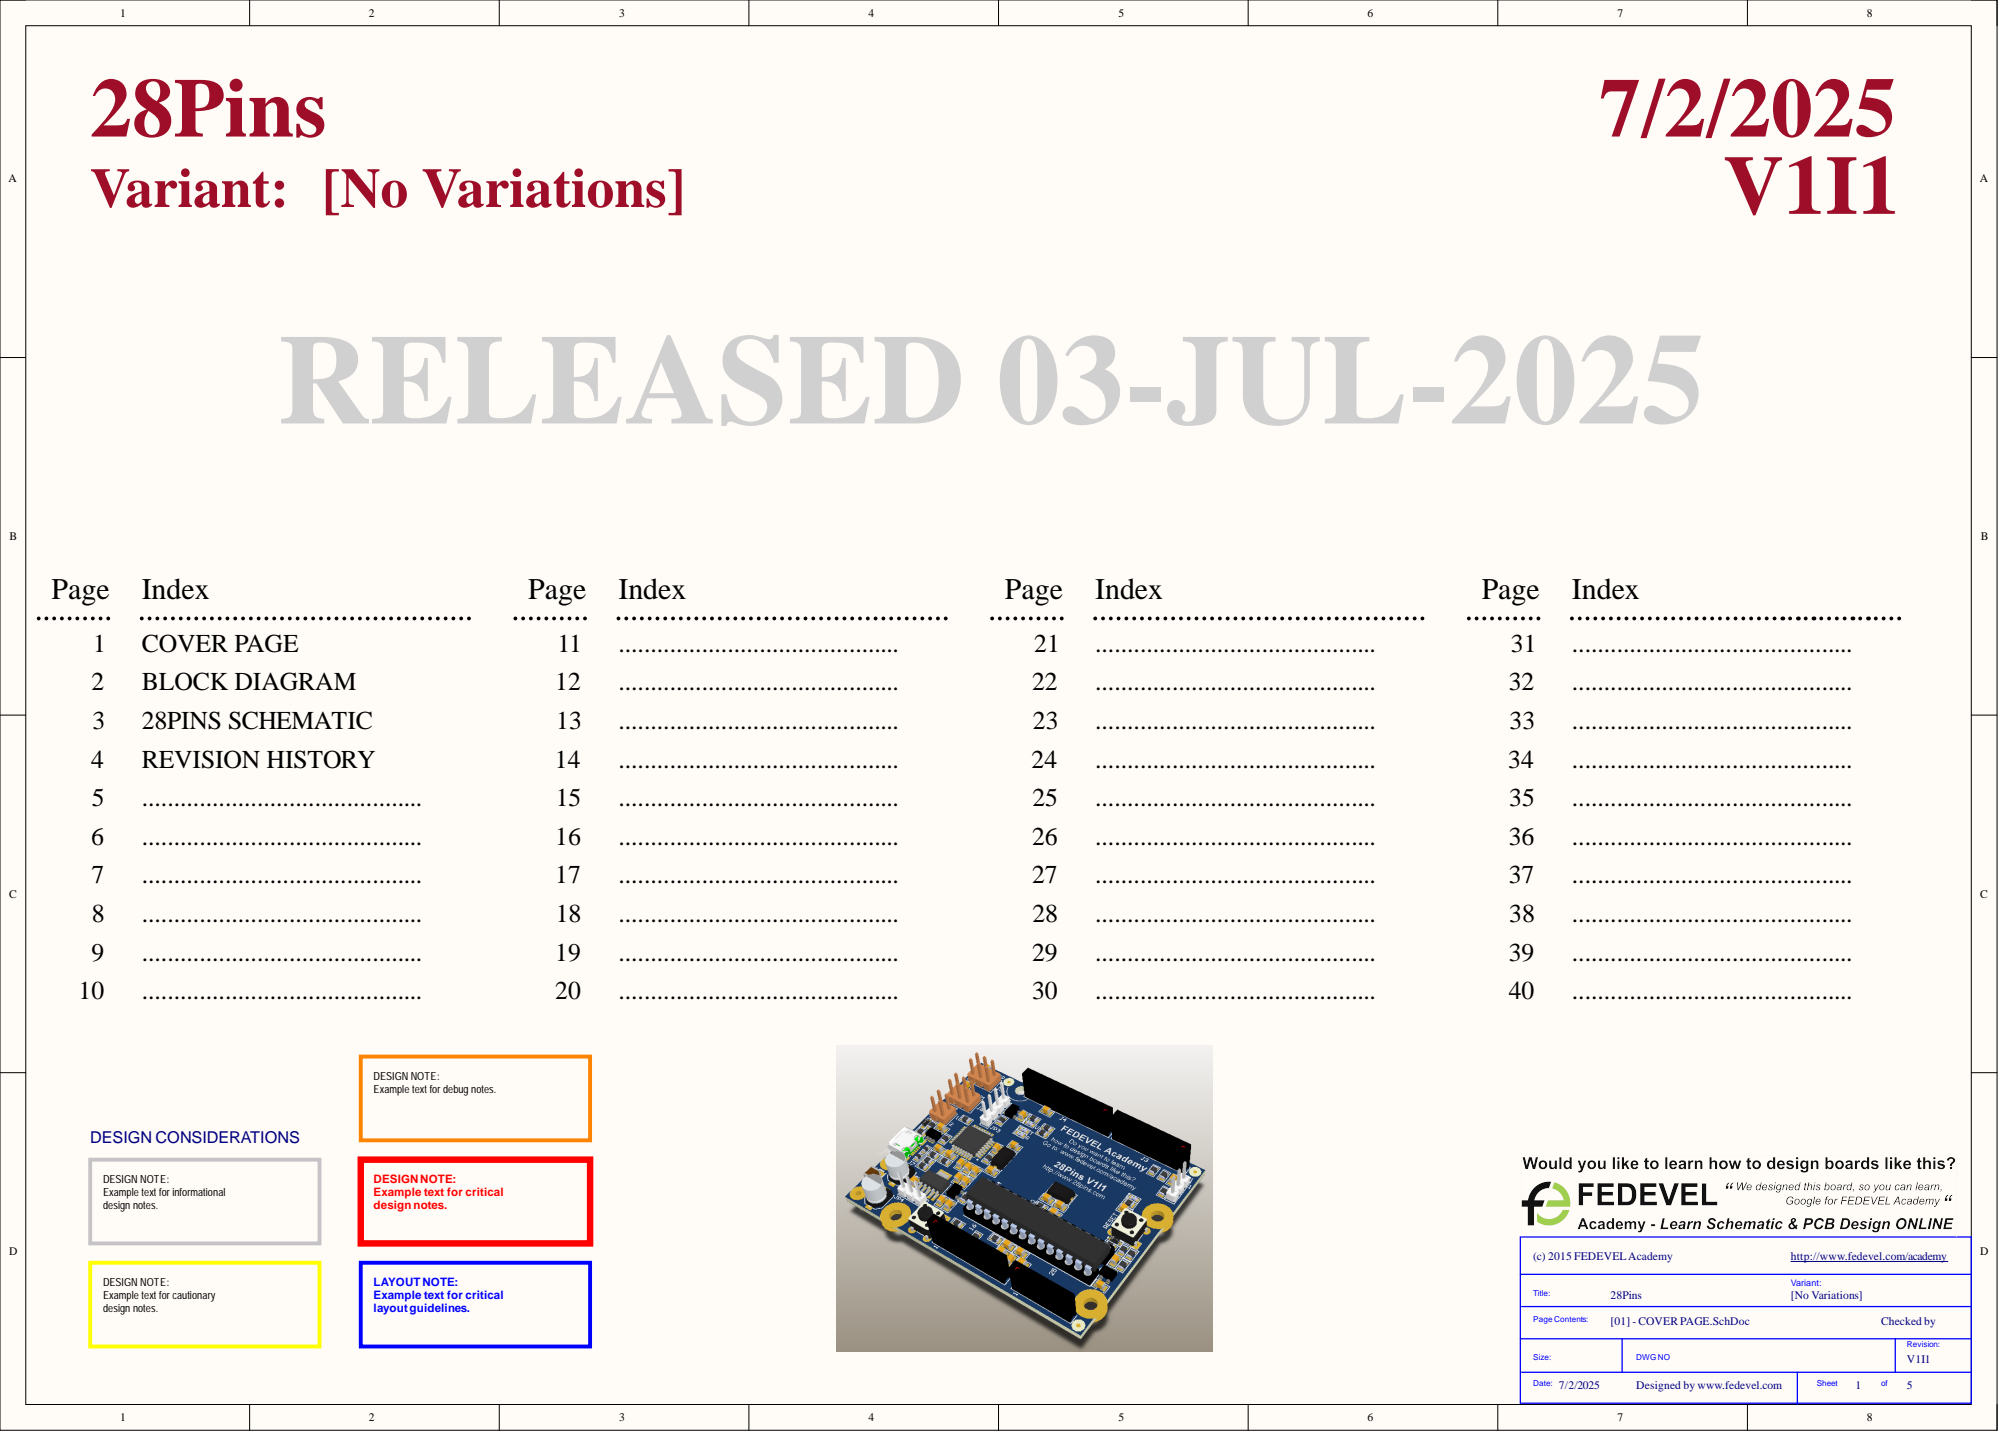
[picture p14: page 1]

DESIGN NOTE:
Example text for debug notes.

Example text for informational
design notes.

Example text for critical

http://www.fedevel.com/academy

Example text for cautionary

LAYOUT NOTE:
layout guidelines.

Size: | DWG NO | Revision: V1I1

Date: 7/2/2025 Designed by www.fedevel.com | Sheet of

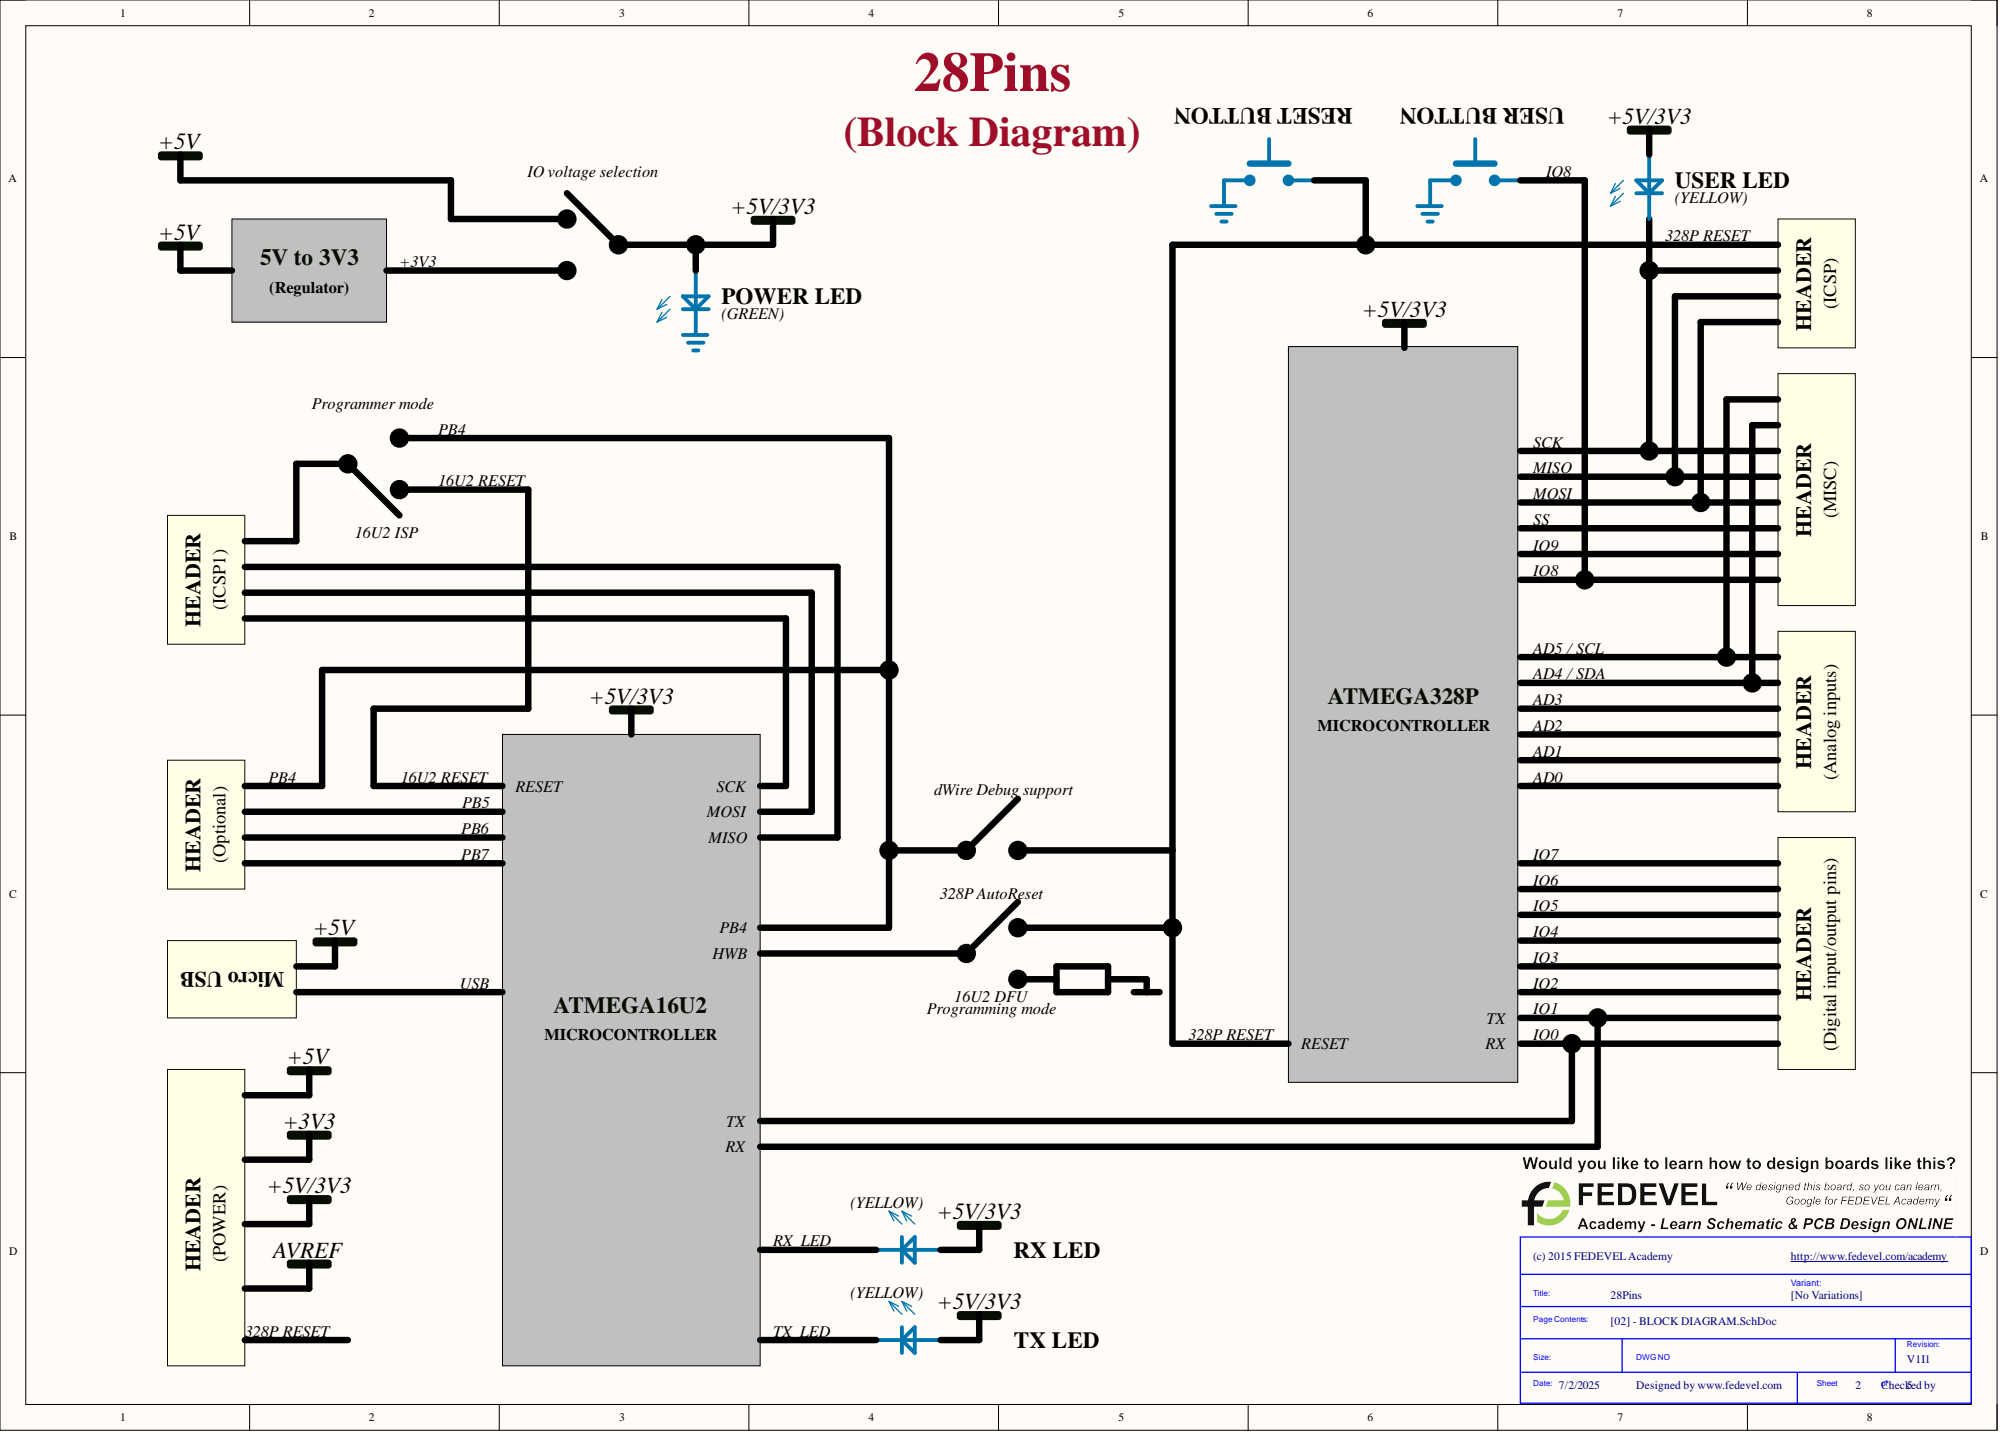
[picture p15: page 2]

MISO
MOSI
SS
IO9
IO8

AD5 / SCL
AD4 / SDA

http://www.fedevel.com/academy


This board supports 5V or 3V3 voltage level on the IO pins:
1) 5V IO - Fit everything as defined in this schematic. NF means, do not fit this component.

2) 3.3V IO - Remove R27, Fit R28, *Replace Y1 (change from 16MHz to 10MHz), *Replace Y2
(change from 16MHz to 8MHz).

3) Both 5V and 3V3, selected through JP4 - Remove R27, Remove R28, Fit JP4, *Replace Y1
(change from 16MHz to
10MHz), *Replace Y2 (change from 16MHz to 8MHz).

*Note: The 16MHz crystals are not recommended for 3.3V operation. We need to adjust
their values, thats why the change.

IMPORTANT: Once you change the crystal value, you may need to re-compile your source
code.

C6 | | 16U2_PB6 | ICSP1

About JP3:
1) DebugWire support - Short 1&2. This was added to support possible debugWire
debugging (programming?) of 328P through 16U2.
In this case, the 16U2 needs to have a correct firmware and has to behave as a debugWire
tool.

Reset (PC1 / dW) 24 UCAP 27 | | 16U2_PB4

16U2_MISO | | J6

2) ISP programmer mode - Short 2&3. In this case, take a cable and connect J5 & J6
together. Upload AVRISP MKII firmware into 16U2 and you can program 328P. Example of
AVRISP MKII firmware can be found at LUFA projects:
http://www.fourwalledcubicle.com/LUFA.php (Tip: remap LEDs of the default AVRISP MKII
LUFA project to the RX and TX LEDs on the 28Pin board)

3) ISP header - Short 3 & 4. In this mode, the ICSP1 header is used as a standard ISP header
to program 16U2 through ISP interaface by an ISP programmer.

About JP1:
1) Autoreset Enabled - Short 1&2. In this case, 16U2 is used to reset 328P when firmware
inside 328P is updated from Arduino IDE.

2) 16U2 DFU mode Enabled - Short 2&3. 16U2 HWB pin is sampled by 16U2 during RESET. If
pulled low, then after Reset the 16U2 will go into DFU mode (it's the mode when you can
flash 16U2 firmware through USB and Atmel Flip software:
http://www.atmel.com/tools/flip.aspx ).

DESIGN NOTE:
This board can be powered from micro USB
connector (J7) or a single +3.3V power rail
(through J1 pin 4). If +3.3V is used, fit R26
and R28. In this case, JP4 & R27 must NOT
be fitted, otherwise the board may be
damaged.

Pin 8 (VIN) is not supported

SCK_R 22R R13 | SCK

MISO

AREF 21 | | SS

PC6/PCINT14/RESET 1 | | IO8

AD5/SCL

PB7/PCINT7/XTAL2/TOSC2 10 | | AD1

Mounting holes 7.4mm pad 3.2mm drill
BOARD MOUNTING HOLES
ONE IN EACH CORNER
FIDUCIALS

GND_2 22 | IO4

IO3
IO2
IO1
IO0

This LED is inverted:
- SCK High = LED OFF
- SCK Low = LED ON

LAYOUT NOTE:
1) Route all the POWER tracks with minimum track width 0.4mm.
2) Route all the other tracks by 0.4mm and change them by the end of
the design to 0.2mm. To change all of them at once, use this filter
"(not InNet('+*') and not InNet('GND')) and IsTrack and (OnLayer('L1')
or OnLayer ('L2'))" and then set 0.2mm width in PCB Inspector panel.

http://www.fedevel.com/academy


http://www.fedevel.com/academy


Mark Not Fitted Components as

DRAFT - Very early stage of schematic, ignore details.
PRELIMINARY - Close to final schematic.
CHECKED - There should not be any mistakes. Tell the engineer if you find one.
RELEASED - A board with this schematic has been sent to production.

http://www.fedevel.com/academy

Designed by www.fedevel.com



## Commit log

2025-07-16 Upload Altium Designer files
    Add schematic and PCB layout images
    [28Pins_Project_V1I1 Project.SchDoc, 28Pins_Project_V1I1.PcbLib, 28Pins_Project_V1I1.PrjPcb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]
2025-07-16 Created Assembly and 3D Files
2025-07-16 Created assembly files
2025-07-16 Created schematic pages
2025-07-16 Create schematics files
2025-07-16 added schematic files
2025-07-16 Rename PCB Layout Preview.png to pcb-layout-preview.png
2025-07-23 Reuploaded edited files
    [28Pins_Project_V1I1 Project.SchDoc, 28Pins_Project_V1I1.PcbLib, 28Pins_Project_V1I1.PrjPcb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]
